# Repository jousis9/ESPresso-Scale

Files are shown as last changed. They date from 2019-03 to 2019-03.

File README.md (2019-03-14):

 **ESPresso Scale**  
Fully open source (s/w & h/w) scale project.

**Main repository of the project is on gitlab**  
https://gitlab.com/jousis/espresso-scale    
**Library only repository**  
https://gitlab.com/jousis/ads1232-library  

**Demo videos**
- https://www.youtube.com/watch?v=8tvMJu86iec
- https://www.youtube.com/watch?v=bEaxTo1kfss
- https://www.youtube.com/watch?v=PEWwwGYqkho
- https://www.youtube.com/watch?v=CMC78F73UXM
- https://www.youtube.com/watch?v=utdwb62cblk
- https://www.youtube.com/watch?v=FwshqRFPCWY
- https://www.youtube.com/watch?v=zp7rjEApNao
- many more coming soon

**Features**
- Open source firmware, software and hardware
- Two pcb designs, one with LED segment display and one with SPI connector (for OLED/TFT)
- Ionic v4 "beta" application with live weight display and full control of scale options (BLE)
- ESP32 (wroom module) MCU
- ADS1232 24-bit ADC from TI
- Lipo and USB powered
- 10SPS and 80SPS sampling speed with various options regarding filtering/smoothing
- Auto calibration function (selectable weight)
- Touch buttons , using ESP32 pins or external touch module (TTP223).
- OTA upgrade mode (wifi)
- 3d printed case (stl & fusion360 files provided)
- power consumption from 50mA under full use (TFT) to <1mA while on deep sleep

**What is provided ?**
- PCB Gerber file
- PCB pictures
- PCB assembly guide
- PCB layer drawings (top/bottom)
- Schematics (PDF)
- PCB easyEDA project export
- Fusion 360 project file for the cases
- stl files for the cases
- Assembly guide (basic)
- Bill of materials (BOM)
- Pinout reference
- Firmware (Arduino IDE project)
- Mobile Application (Ionic v4 source code)
- Basic ADC settings explanation file and some basic tests

**Documentation**  
All the source files have a lot of comments inside but I will upload separate, more detailed documents, soon.

**Consider contributing**  
I am not a developher, nor an EE.  
This project is intended as a kick start for the community to build something awesome.  
Feel free to change anything in any way you see fit.  
If you want to read more technical stuff and reasons why I did what I did, check out this [hackaday page](https://hackaday.io/project/164256-espresso-scale).  
I will try to upload details about all aspects of the design.  

**License**  
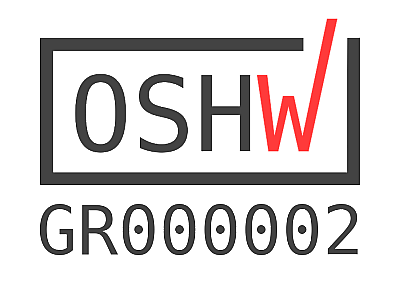
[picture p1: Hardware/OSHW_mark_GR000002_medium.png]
OSHW Certification
  
Software under [GPL v3](https://gitlab.com/jousis/espresso-scale/blob/master/LICENSE)  
Hardware under [CERN Open Hardware Licence v1.2](https://gitlab.com/jousis/espresso-scale/blob/master/hw-LICENSE)  
Documentation under [CC BY-SA license 2.0](https://creativecommons.org/licenses/by-sa/2.0/)

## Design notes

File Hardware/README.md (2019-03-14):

**About AVDD/Excitation voltage**  
I am testing 5V,4.3V LDOs for AVDD to see if the PCB can achieve +/-0.005 usable resolution when plugged in to 5V source.   
When my source voltage is 5V (usb wall charger) I get 4.73V on the AVDD LDO input (don't forget our BAT20J voltage drop). No need to force it to 3.3V (as in the proposed BOM).  
Note that the analog LDO gets its input directly from the P-Channel MOSFET and is not constrained by our digital voltage LDO. We can use 5V LDO for analog excitation voltage and 3.3 for the rest.  
The proposed TLV75533PDBVR for the DVDD we can go up to 5.5V input, so if you wish to increase the input voltage, be careful.  

**Upcoming changes (March 2019)**    
-Trying out touch button solutions because the internal capacitive sensors of ESP32 are not so good behind plastic.  
-I changed (again) the RC filters. X2Y are gone (are expensive, difficult to find and could not measure any difference) and I'm going back to 100% ADS1232 reference design with simple RC plus some more passthrough EMI filters (0805 on this section)

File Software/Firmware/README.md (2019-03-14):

  
**Some usefull documents from TI you should read**  
[ADS1232 datasheet](http://www.ti.com/lit/ds/symlink/ads1232.pdf)  
[ADS1232 Reference board User's Guide](http://www.ti.com/lit/ug/sbau120b/sbau120b.pdf)  
[High-Resolution, Low-Drift, Precision Weigh-Scale Reference Design with AC Bridge Excitation](http://www.ti.com/lit/ug/tiduac1a/tiduac1a.pdf)  

**Other libraries you might like**  

HX711 library from olkal and with a simple and efficient filtering function (moving average with High/Low Rejection)  
https://github.com/olkal/HX711_ADC  
  
If you need more channels and a more elaborate ADC read function, check out ADS123X library by Hamid Saffari  
https://github.com/HamidSaffari/ADS123X  
  
Another ADS1232 library with different approach (spitransfer) from jeffkub  
https://github.com/jeffkub/beer-gauge/tree/master/firmware/beer-gauge  
  
And last but not least, the famous HX711 from bodge  
https://github.com/bogde/HX711

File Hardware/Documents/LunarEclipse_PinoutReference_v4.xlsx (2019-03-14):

PIN | GPIO | ALT NAME | WARNING | TOUCH | I/O | INT PULLUP/PULLDOWN | H/W SPI | RTC | ADC | SCALE FUNCTION
4 | 36 | SVP |  |  | I | N |  | RTC_GPIO0 | 1
5 | 39 | SVN |  |  | I | N |  | RTC_GPIO3 | 1
6 | 34 |  |  |  | I | N |  | RTC_GPIO4 | 1
7 | 35 |  |  |  | I | N |  | RTC_GPIO5 | 1
8 | 32 |  |  | T9 | I/O |  |  | RTC_GPIO9 | 1 | T9
9 | 33 |  |  | T8 | I/O |  |  | RTC_GPIO8 | 1 | T8
10 | 25 |  |  |  | I/O |  |  | RTC_GPIO6 | 2
11 | 26 |  |  |  | I/O |  |  | RTC_GPIO7 | 2
12 | 27 |  |  | T7 | I/O |  |  | RTC_GPIO17 | 2
13 | 14 | HSPI SCK |  | T6 | I/O |  | 1 | RTC_GPIO16 | 2 | T6
14 | 12 | HSPI MISO | KEEP LOW ON RESET (DEFAULT) | T5 | I/O |  | 1 | RTC_GPIO15 | 2 | GAIN0
16 | 13 | HSPI MOSI |  | T4 | I/O |  | 1 | RTC_GPIO14 | 2 | GAIN1
17 | 9 |  | DO NOT USE |  | I/O
18 | 10 |  | DO NOT USE |  | I/O
19 | 11 |  | DO NOT USE |  | I/O
20 | 6 |  | DO NOT USE |  | I/O
21 | 7 |  | DO NOT USE |  | I/O
22 | 8 |  | DO NOT USE |  | I/O
23 | 15 | HSPI SS / MTDO | KEEP HIGH ON RESET (DEFAULT) | T3 | I/O |  | 1 | RTC_GPIO13 | 2
24 | 2 |  | KEEP LOW ON RESET (DEFAULT) / IF HIGH CANNOT DOWNLOAD FIRMWARE | T2 | I/O |  |  | RTC_GPIO12 | 2
25 | 0 | boot |  | T1 | I/O |  |  | RTC_GPIO11 | 2 | IO0 button
26 | 4 |  |  | T0 | I/O |  |  | RTC_GPIO10 | 2 | ADC_PDWN
27 | 16 |  |  |  | I/O |  |  |  |  | ADC_DOUT
28 | 17 |  |  |  | I/O |  |  |  |  | ADC_SCLK
29 | 5 | VSPI SS |  |  | I/O |  | 2 |  |  | MAX7221 CS
30 | 18 | VSPI SCK |  |  | I/O |  | 2 |  |  | MAX7221 CLK
31 | 19 | VSPI MISO |  |  | I/O |  | 2
33 | 21 |  |  |  | I/O
34 | 3 | RXD | NC |  | I/O |  |  |  |  | RXD0
35 | 1 | TXD | NC |  | I/O |  |  |  |  | TXD0
36 | 22 |  |  |  | I/O |  |  |  |  | ADC_SPEED
37 | 23 | VSPI MOSI | or D1 or SDI |  | I/O |  | 2 |  |  | MAX7221 INPUT

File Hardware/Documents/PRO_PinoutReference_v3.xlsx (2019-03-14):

PIN | GPIO | ALT NAME |  | WARNING | TOUCH | I/O | INT PULLUP/PULLDOWN | H/W SPI | RTC | ADC | SCALE FUNCTION
4 | 36 | SVP |  |  |  | I | N |  | RTC_GPIO0 | 1 | BAT_CHECK
5 | 39 | SVN |  |  |  | I | N |  | RTC_GPIO3 | 1
6 | 34 |  |  |  |  | I | N |  | RTC_GPIO4 | 1
7 | 35 |  |  |  |  | I | N |  | RTC_GPIO5 | 1
8 | 32 |  |  |  | T9 | I/O |  |  | RTC_GPIO9 | 1 | T9 / CN8
9 | 33 |  |  |  | T8 | I/O |  |  | RTC_GPIO8 | 1 | T8 / CN7
10 | 25 |  |  |  |  | I/O |  |  | RTC_GPIO6 | 2 | SCREEN_BL
11 | 26 |  |  |  |  | I/O |  |  | RTC_GPIO7 | 2 | SCREEN_DC
12 | 27 |  |  |  | T7 | I/O |  |  | RTC_GPIO17 | 2 | SCREEN_RES
13 | 14 | HSPI SCK | OLED D0 or SCK or CLK or SCL |  | T6 | I/O |  | 1 | RTC_GPIO16 | 2 | SCREEN_SCL
14 | 12 | HSPI MISO | OLED SDO | KEEP LOW ON RESET (DEFAULT) | T5 | I/O |  | 1 | RTC_GPIO15 | 2 | T5 / CN6
16 | 13 | HSPI MOSI | OLED D1 or SDA or DIN |  | T4 | I/O |  | 1 | RTC_GPIO14 | 2 | SCREEN_SDA
17 | 9 |  |  | DO NOT USE |  | I/O
18 | 10 |  |  | DO NOT USE |  | I/O
19 | 11 |  |  | DO NOT USE |  | I/O
20 | 6 |  |  | DO NOT USE |  | I/O
21 | 7 |  |  | DO NOT USE |  | I/O
22 | 8 |  |  | DO NOT USE |  | I/O
23 | 15 | HSPI SS / MTDO |  | KEEP HIGH ON RESET (DEFAULT) | T3 | I/O |  | 1 | RTC_GPIO13 | 2 | SCREEN_CS
24 | 2 |  |  | KEEP LOW ON RESET (DEFAULT) / IF HIGH CANNOT DOWNLOAD FIRMWARE | T2 | I/O |  |  | RTC_GPIO12 | 2 | INDICATOR LED
25 | 0 | boot |  |  | T1 | I/O |  |  | RTC_GPIO11 | 2 | IO0 button
26 | 4 |  |  |  | T0 | I/O |  |  | RTC_GPIO10 | 2
27 | 16 |  |  |  |  | I/O |  |  |  |  | ADC_GAIN0
28 | 17 |  |  |  |  | I/O |  |  |  |  | ADC_GAIN1
29 | 5 | VSPI SS |  |  |  | I/O |  | 2 |  |  | ADC_PDWN
30 | 18 | VSPI SCK |  |  |  | I/O |  | 2 |  |  | ADC_SCLK
31 | 19 | VSPI MISO |  |  |  | I/O |  | 2 |  |  | ADC_DOUT
33 | 21 |  |  |  |  | I/O |  |  |  |  | ADCLDO_EN
34 | 3 | RXD |  | NC |  | I/O |  |  |  |  | RXD0
35 | 1 | TXD |  | NC |  | I/O |  |  |  |  | TXD0
36 | 22 |  |  |  |  | I/O |  |  |  |  | ADC_SPEED
37 | 23 | VSPI MOSI |  | or D1 or SDI |  | I/O |  | 2 |  |  | BAT_CHECK_EN

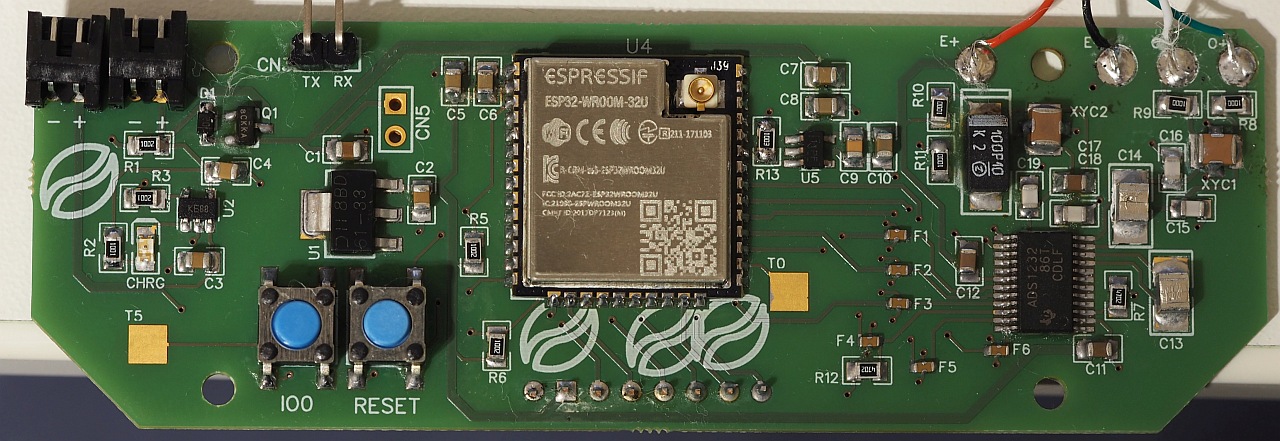
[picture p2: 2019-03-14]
Hardware/PCB Images/PRO v2/top_small.jpg

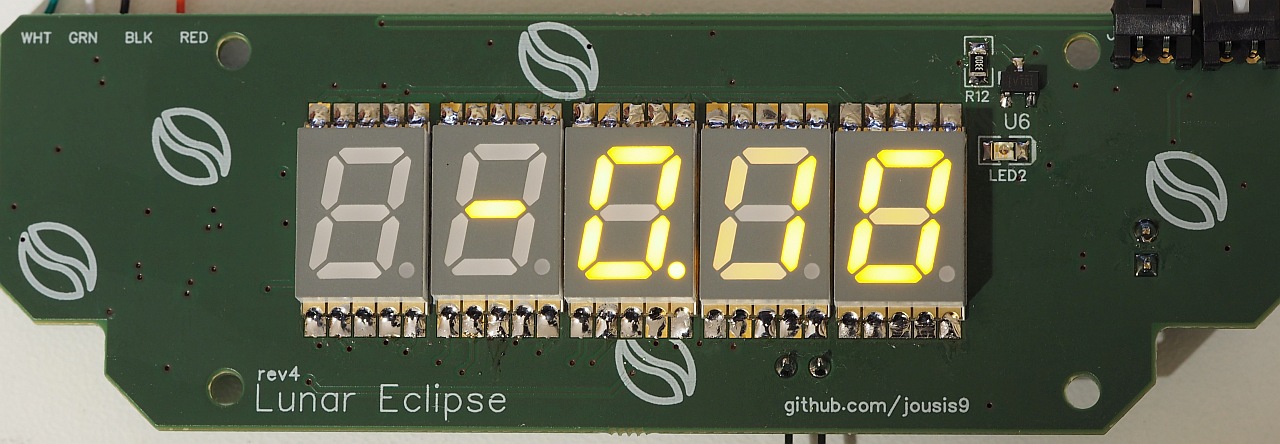
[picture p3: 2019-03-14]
Hardware/PCB Images/Lunar Eclipse v4/bottom_small.jpg

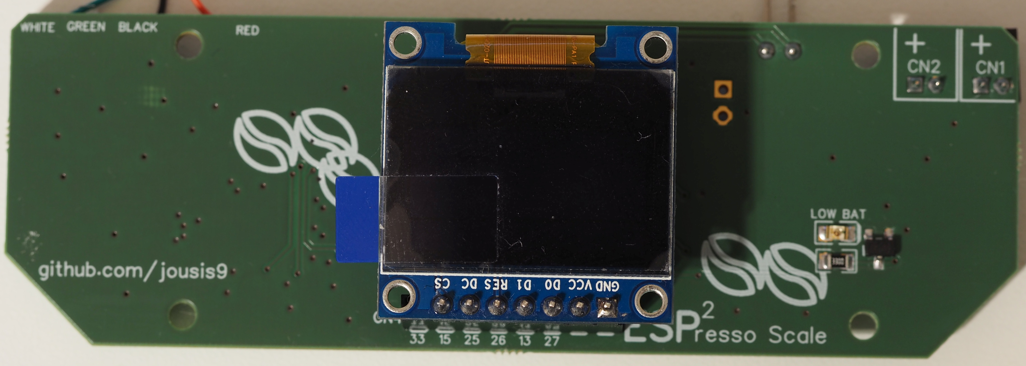
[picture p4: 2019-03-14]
Hardware/PCB Images/PRO v2/bottom02.jpg

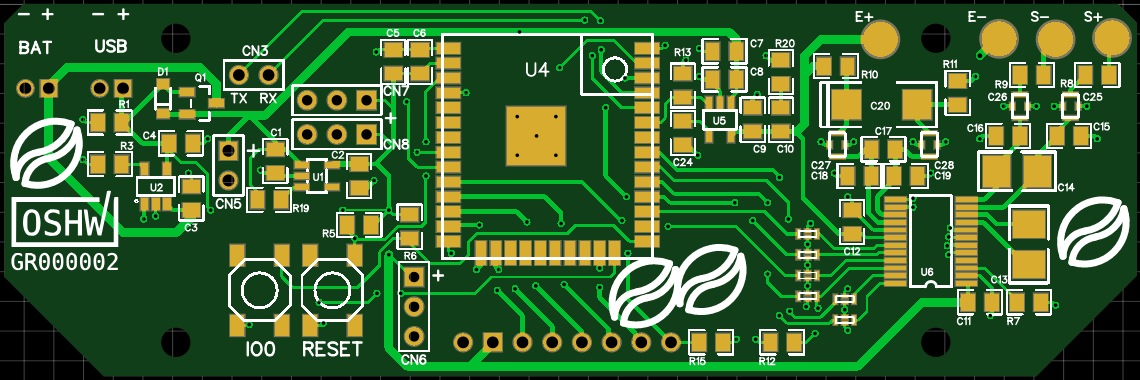
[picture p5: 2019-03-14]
Hardware/PCB Layers/PRO v3/TopRender.jpg

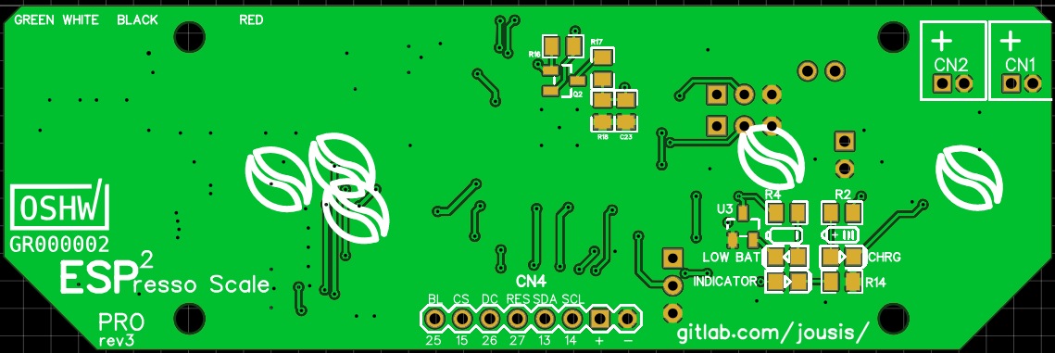
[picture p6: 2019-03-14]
Hardware/PCB Layers/PRO v3/BottomRender.jpg

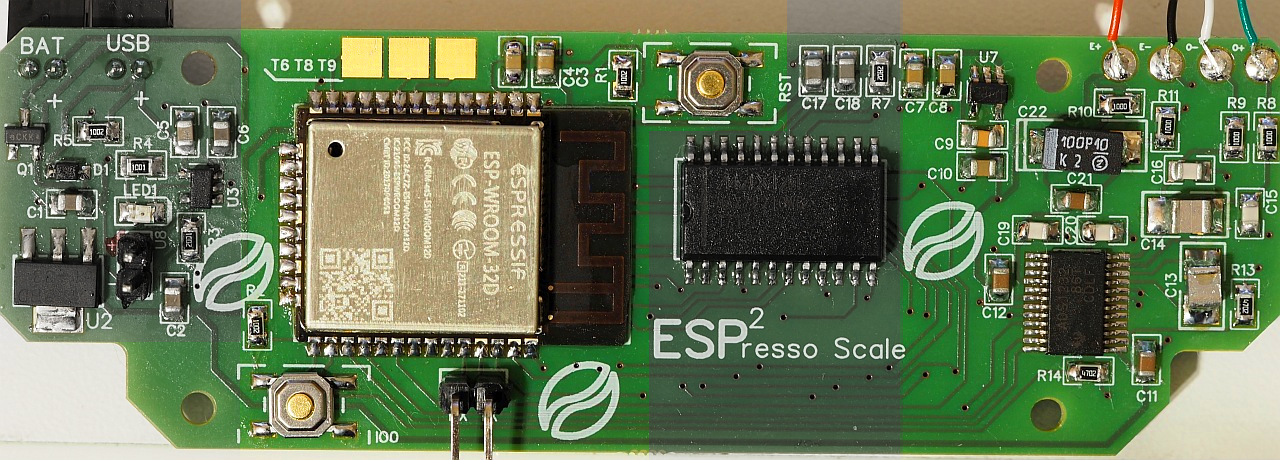
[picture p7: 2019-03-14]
Hardware/PCB Images/Lunar Eclipse v4/top_sections.jpg

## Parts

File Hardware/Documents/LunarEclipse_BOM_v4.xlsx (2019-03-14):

ID | Name | Designator | Footprint | quick info | Quantity | Can I use cheaper ? | Manufacturer Part | Manufacturer | Supplier | cost (euro for 1 unit) | Supplier URL
1 | VDMY10C0 | 7SEG1,7SEG2,7SEG3,7SEG4,7SEG5 | VDMY10C0 |  | 5 | YES | KCSC03-106 | VISHAY | mouser | 7.75 | https://gr.mouser.com/ProductDetail/VDMY10C0/
2 | Mini Push Button | BOOT,RESET | SMD-BUTTON |  | 2 | Definitely, I just like them a lot. Check the buttons of PRO version. | COM-08720 | SparkFun Electronics | mouser | 1.66 | https://gr.mouser.com/ProductDetail/COM-08720/
3 | 4.7uF | C1,C2,C6 | 0805 | 4.7uF, 16V | 3 | YES | GRM21BR71C475KE51L | murata | mouser | 0.63 | https://gr.mouser.com/ProductDetail/GRM21BR71C475KE51L/
4 | 10uF | C3,C7,C10,C17 | 0805 | 10uF, 16V | 4 | YES | GRM21BC81C106KE15K | murata | mouser | 0.664 | https://gr.mouser.com/ProductDetail/GRM21BC81C106KE15K/
5 | 0.1uF | C4,C8,C18 | 0805 | 0.1uF, 16V | 3 | YES | CC0805JRX7R7BB104 | yageo | mouser | 0.471 | https://gr.mouser.com/ProductDetail/CC0805JRX7R7BB104/
6 | 10nF | C9 | 0805 | 0.01uF (10nF), 50V | 1 | YES | 885012207092 | Wurth | mouser | 0.08 | https://gr.mouser.com/ProductDetail/710-885012207092/
7 | 2.2uF | C11,C12,C21 | 0805 | 2.2uF, 16V | 3 | YES | GCM21BR71A225JA37L | murata | mouser | 1.101 | https://gr.mouser.com/ProductDetail/GCM21BR71A225JA37L/
8 | 0.1uF PPS | C13,C14 | 1210 | 0.1uF PPS, 16V | 2 | Might lose accuracy/stability | ECH-U1C104GX5 | Panasonic | mouser | 1.484 | https://gr.mouser.com/ProductDetail/667-ECH-U1C104GX5/
9 | 1uF | C5 | 0805 | 1uF, 16V | 1 | YES | GRM21BR71C105JA01K | murata | mouser | 0.157 | https://gr.mouser.com/ProductDetail/GRM21BR71C105JA01K/
10 | 100pF NP0 | C15,C16,C19,C20 | 0805 | 100pF, NP0, 50V, 1% | 4 | Might lose accuracy/stability | GRM2165C1H101FA01D | Murata | mouser | 0.664 | https://gr.mouser.com/ProductDetail/0805YA101FAT2A/
11 | 100uF (T) | C22 | Case C | 100uF, Tantalum, 10V | 1 | YES | TP3C107K010D0900AS | VISHAY | mouser | 0.568 | https://gr.mouser.com/ProductDetail/TP3C107K010D0900AS/
12 | BAT20JFILM | D1 | SOD-323 |  | 1 | YES | BAT20JFILM | STMicroelectronics | mouser | 0.332 | https://gr.mouser.com/ProductDetail/BAT20JFILM/
13 | DF3A-2P-2DS | CN1,CN2 |  |  | 2 | YES | DF3A-2P-2DS | Hirose | mouser | 0.175 | https://gr.mouser.com/ProductDetail/DF3A-2P-2DS/ | 2mm pitch, 0.8mm hole. DF3A-2P-2DS(16) ==> right angle, tin plating , blue color, DF3A-2P-2DS ==> right angle, black , df3-2p-2ds(01) ==> right angle, gold plating, black NOTE: DS ==> right angle DSA==> straight
14 | Yellow | LED1 | 0805 | 2V, 20mA | 1 | YES | 150080YS75000 | Wurth | mouser | 0.16 | https://gr.mouser.com/ProductDetail/150080YS75000/
15 | Red | LED2 | 0805 | 1.75V , for low battery warning | 1 | YES | APTD2012LSURCK | Kingbright | mouser | 0.402 | https://gr.mouser.com/ProductDetail/604-APTD2012LSURCK
16 | SQ2303ES-T1_GE3 | Q1 | SOT-23(SOT-23-3) |  | 1 | YES | SQ2303ES-T1_GE3 | VISHAY | mouser | 0.437 | https://gr.mouser.com/ProductDetail/SQ2303ES-T1_GE3/
17 | 10K | R1,R2,R5 | 0805 | 10K, 1% | 3 | YES | ERJ-6ENF1002V | Panasonic | mouser | 0.261 | https://gr.mouser.com/ProductDetail/ERJ-6ENF1002V/
18 | 2K | R3 | 0805 | 2K, 1% | 1 | YES | ERJ-6ENF2001V | Panasonic | mouser | 0.087 | https://gr.mouser.com/ProductDetail/ERJ-6ENF2001V/
19 | 1K | R4 | 0805 | 1K, 1% | 1 | YES | ERJ-6ENF1001V | Panasonic | mouser | 0.087 | https://gr.mouser.com/ProductDetail/ERJ-6ENF1001V/
20 | 47K | R13,R14 | 0805 | 47K,1% | 2 | YES | ERJ-6ENF4702V | Panasonic | mouser | 0.49 | https://www.mouser.com/ProductDetail/667-ERJ-6ENF4702V/
21 | 28K (production) | R7 | 0805 | alternative : 18K ERJ-6GEYJ183V | 1 | YES | ERJ-6ENF2802V | Panasonic | mouser | 0.236 | https://gr.mouser.com/ProductDetail/ERJ-6ENF2802V/
22 | 100R | R8,R9,R10,R11 | 0805 | 100R, 1% | 4 | Might lose accuracy/stability | ERJ-6ENF1000V | Panasonic | mouser | 0.348 | https://gr.mouser.com/ProductDetail/ERJ-6ENF1000V/
23 | 330R | R12 | 0805 | 330R | 1 | YES | CRCW0805330RFKEAC | VISHAY | mouser | 0.087 | https://gr.mouser.com/ProductDetail/71-CRCW0805330RFKEAC/
24 | ESP32-WROOM-32D | U1 | ESP32_WROOM_FOOTPRINT |  | 1 | YES | ESP32-WROOM-32D | Espressif | mouser | 3.32 | https://gr.mouser.com/ProductDetail/356-ESP32WROOM-32D/
25 | AP7361C-33E-13 | U2 | SOT223-4 | main LDO (1A) | 1 | YES | AP7361C-33E-13 | Diodes Incorporated | mouser | 0.498 | https://gr.mouser.com/ProductDetail/AP7361C-33E-13/
26 | MCP73831T-2ATI/OT | U3 | SOT-23-5 |  | 1 | YES | MCP73831T-2ATI/OT | MICROCHIP | mouser | 0.507 | https://gr.mouser.com/ProductDetail/MCP73831T-2ATI-OT/
27 | ADS1232IPWR | U4 | TSSOP-24 |  | 1 | r u kidding me ? | ADS1232IPWR | TI | mouser | 7.13 | https://gr.mouser.com/ProductDetail/ADS1232IPWR/
28 | MAX7221CWG+ | U5 | SOIC-24 |  | 1 | YES | MAX7221CWG+ | maxim integrated | mouser | 8.03 | https://gr.mouser.com/ProductDetail/700-MAX7221CWG/
29 | Voltage supervisor | U6 | SOT-23-3 | 2.93V, Active-low,Push-pull | 1 | Yes, you can also completely remove it, along with LED2 and R12 | TLV809K33DBVR | TI | mouser | 0.576 | https://gr.mouser.com/ProductDetail/595-TLV809K33DBVR
30 | TPS7A0533PDBVR | U7 | SOT-23-5 | ADC LDO (200mA) | 1 | Yes, use any other, but of high quality | TPS7A0533PDBVR | TI | mouser | 0.515 | https://gr.mouser.com/ProductDetail/595-TPS7A0533PDBVR/
31 | lipo battery |  |  | 1600mAh | 1 | YES |  |  | grobotronics | 12 | https://grobotronics.com/polymer-lithium-ion-battery-3.7v-1600mah.html
32 | load cell |  |  | 200g-500g high precision for espresso, 500g+ for other | 1 | YES |  |  | aliexpress | 4 | https://www.aliexpress.com/item/200g-small-range-high-precision-weighing-sensor-load-cell-weight-sensor/32746278566.html
 | Male headers 1x2 for VIN (optional) | U8 |  |  |  |  |  | Total Cost |  | 54.91 | excl VAT
 | Male headers 1x2 for serial | U9

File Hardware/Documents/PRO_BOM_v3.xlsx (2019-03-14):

ID | Name | Designator | Footprint | quick info | Quantity | Try Cheaper ? | Manufacturer Part | Manufacturer | Supplier | cost (euro for 1 unit) | Supplier URL
1 | 4.7u | C2,C3,C4,C10 | 0805 | 4.7uF, 16V | 4 | YES | GRM21BR71C475KE51L | murata | mouser | 0.84 | https://gr.mouser.com/ProductDetail/GRM21BR71C475KE51L/
2 | 1u | C1,C7 | 0805 | 1uF, 16V | 2 | YES | GRM21BR71C105JA01K | murata | mouser | 0.314 | https://gr.mouser.com/ProductDetail/GRM21BR71C105JA01K/
3 | 10u | C5 | 0805 | 10uF, 16V | 1 | YES | GRM21BC81C106KE15K | murata | mouser | 0.166 | https://gr.mouser.com/ProductDetail/GRM21BC81C106KE15K/
4 | 0.1u | C6,C8,C23 | 0805 | 0.1uF, 16V | 3 | YES | CC0805JRX7R7BB104 | yageo | mouser | 0.471 | https://gr.mouser.com/ProductDetail/CC0805JRX7R7BB104/
5 | 10n | C9 | 0805 | 0.01uF (10nF), 50V | 1 | YES | 885012207092 | Wurth | mouser | 0.08 | https://gr.mouser.com/ProductDetail/710-885012207092/
6 | 10n | C24 | 0805 | Optional 0.01uF for low noise, read assembly guide | 1 | YES | 885012207092 | Wurth | mouser | 0.08 | https://gr.mouser.com/ProductDetail/710-885012207092/
7 | 2.2u | C17 | 0805 | 2.2uF, 16V | 1 | Might lose accuracy/stability | GCM21BR71A225JA37L | murata | mouser | 0.367 | https://gr.mouser.com/ProductDetail/GCM21BR71A225JA37L/
8 | 2.2u | C11,C12 | 0805 | 2.2uF, 16V | 2 | YES | VJ0805G225KXQTW1BC | VISHAY | mouser | 0.314 | https://gr.mouser.com/ProductDetail/77-VJ0805G225KXQTBC/
9 | 0.1u PPS ECH-U1C104GX5 | C13,C14 | 1210 | 0.1uF PPS, 16V | 2 | Might lose accuracy/stability | ECH-U1C104GX5 | Panasonic | mouser | 1.484 | https://gr.mouser.com/ProductDetail/667-ECH-U1C104GX5/
10 | 100p NP0 | C15,C16,C18,C19 | 0805 | 100pF, NP0, 50V, 1% | 4 | Might lose accuracy/stability | GRM2165C1H101FA01D | Murata | mouser | 0.664 | https://gr.mouser.com/ProductDetail/GRM2165C1H101FA01D/
11 | 100uF (T) | C20 | Case C | 100uF, Tantalum, 10V | 1 | YES | TP3C107K010D0900AS | VISHAY | mouser | 0.568 | https://gr.mouser.com/ProductDetail/TP3C107K010D0900AS/
12 | 1u feed through | C25,C26,C27,C28 | 0805 | 1uF Feed through | 4 | Might lose accuracy/stability | NFM21PC105B1C3D | Murata | mouser | 0.84 | https://gr.mouser.com/ProductDetail/NFM21PC105B1C3D/
13 | DF3A-2P-2DS | CN1,CN2 | DF3A-2P-2DS | power/battery connector | 2 | YES | DF3A-2P-2DS | Hirose | mouser | 0.175 | https://gr.mouser.com/ProductDetail/DF3A-2P-2DS/
14 | 2.54_HEADER_2P | CN3,CN5 | 2P_2.54 | serial/5V bypass power | 1
15 | Header-M2.54_1x8 | CN4 | 210S-1X8P | oled/tft SPI connector | 1
16 | Header1x3_2.54 | CN6,CN7,CN8 |  | external buttons | 3
17 | BAT20JFILM | D1 | SOD-323 |  | 1 | YES | BAT20JFILM | STMicroelectronics | mouser | 0.332 | https://gr.mouser.com/ProductDetail/BAT20JFILM/
18 | 100pF feed through | F1,F2,F3,F4,F5,F6 | 0603 | feed through caps for the digital signal lines of the ADC. Works fine without them. | 6 | Yes,you can also omit them but be carefull not to short with G when using bypass cable :) | NFM18CC101R1C3D | MuRata | mouser | 1.572 | https://gr.mouser.com/ProductDetail/81-NFM18CC101R1C3D/
19 | CHRG | LED1 | 0805 | 2V, 20mA | 1 | YES | 150080YS75000 | Wurth | mouser | 0.16 | https://gr.mouser.com/ProductDetail/150080YS75000/
20 | LOW BAT | LED2 | 0805 | 1.75V , for low battery warning | 1 | YES | APTD2012LSURCK | Kingbright | mouser | 0.402 | https://gr.mouser.com/ProductDetail/604-APTD2012LSURCK/
21 | INDICATOR | LED3 | 0805 | 2V, 20mA | 1 | Yes, you can also omit it | 150080BS75000 | Wurth | mouser | 0.16 | https://gr.mouser.com/ProductDetail/150080BS75000/
22 | SQ2303ES-T1_GE3 | Q1,Q2 | SOT-23(SOT-23-3) |  | 2 | YES | SQ2303ES-T1_GE3 | VISHAY | mouser | 0.874 | https://gr.mouser.com/ProductDetail/SQ2303ES-T1_GE3/
23 | 10k | R1,R5,R6,R17,R18 | 0805 | 10K, 1% | 5 | YES | ERJ-6ENF1002V | Panasonic | mouser | 0.435 | https://gr.mouser.com/ProductDetail/ERJ-6ENF1002V/
24 | 1k | R2,R15 | 0805 | 1K, 1% | 1 | YES | ERJ-6ENF1001V | Panasonic | mouser | 0.087 | https://gr.mouser.com/ProductDetail/ERJ-6ENF1001V/
25 | 2k | R3 | 0805 | 2K, 1% | 1 | YES | ERJ-6ENF2001V | Panasonic | mouser | 0.087 | https://gr.mouser.com/ProductDetail/667-ERJ-6ENF2001V/
26 | 330R | R4,R14 | 0805 | 330R, 1% | 1 | YES | CRCW0805330RFKEAC | VISHAY | mouser | 0.087 | https://gr.mouser.com/ProductDetail/71-CRCW0805330RFKEAC/
27 | 47K | R7,R12 | 0805 | 47K,1% | 2 | YES | ERJ-6ENF4702V | Panasonic | mouser | 0.49 | https://www.mouser.com/ProductDetail/667-ERJ-6ENF4702V/
28 | 100R | R10,R11 | 0805 | 100R, 1% | 4 | YES | ERJ-6ENF1000V | Panasonic | mouser | 0.348 | https://gr.mouser.com/ProductDetail/ERJ-6ENF1000V/
29 | 0R | R8,R9 | 0805 | 0R, 1% | 2 | YES | RC0805FR-130RL | Yageo | mouser | 0.192 | https://gr.mouser.com/ProductDetail/603-RC0805FR-130RL/
30 | 100K | R13,R16,R19 | 0805 | 100K, 1% | 3 | YES | ERJ-6ENF1003V | Panasonic | mouser | 0.261 | https://gr.mouser.com/ProductDetail/667-ERJ-6ENF1003V/
31 | ???R | R20 | 0805 | optional, to add some R to the output of the LDO. More info on assembly guide.
32 | RESET | SW1 |  |  | 1 | YES | PTS525SM15SMTR2LFS | C&K | mouser | 0.288 | https://gr.mouser.com/ProductDetail/611-PTS525SM15SMTR2/
33 | IO0 | SW2 |  |  | 1 | YES | PTS525SM15SMTR2LFS | C&K | mouser | 0.288 | https://gr.mouser.com/ProductDetail/611-PTS525SM15SMTR2/
34 | TLV75533PDBVR | U1 | SOT-23-5 | main LDO (500mA) | 1 | YES | TLV75533PDBVR | TI | mouser | 0.541 | https://gr.mouser.com/ProductDetail/595-TLV75533PDBVR/
35 | MCP73831T-2ATI/OT | U2 | SOT-23-5 |  | 1 | YES | MCP73831T-2ATI/OT | MICROCHIP | mouser | 0.507 | https://gr.mouser.com/ProductDetail/MCP73831T-2ATI-OT/
36 | TLV809K33DBVR | U3 | SOT-23-3 | 2.93V, Active-low,Push-pull | 1 | Yes, it is only for low battery warning... you can completely remove it, along with LED2 and R12 | TLV809K33DBVR | TI | mouser | 0.576 | https://gr.mouser.com/ProductDetail/595-TLV809K33DBVR
37 | ESP32_ESP_WROOM_32U | U4 | ESP32_ESP_WROOM_32U |  | 1 | Yes, use any other with same footprint (ex. 32D with antenna) | ESP32-WROOM-32U | Espressif | mouser | 3.49 | https://gr.mouser.com/ProductDetail/ESP32-WROOM-32U/
38 | TPS7A0533PDBVR | U5 | SOT-23-5 | ADC LDO (200mA) | 1 | Yes, use any other, but of high quality. Try one with 4.7-5Voutput | TPS7A0533PDBVR | TI | mouser | 0.515 | https://gr.mouser.com/ProductDetail/595-TPS7A0533PDBVR/
39 | ADS1232IPWR | U6 | TSSOP-24 |  | 1 | r u kidding me ? | ADS1232IPWR | TI | mouser | 7.13 | https://gr.mouser.com/ProductDetail/ADS1232IPWR/
40 | OLED/TFT with SPI interface (can also use any other interface using the same pins). Be carefull with VCC/GND pins. Might be the other way around. |  |  |  | 1 | YES |  |  | aliexpress | 3 | https://www.aliexpress.com/item/IPS-0-96-inch-7P-SPI-HD-65K-Full-Color-LCD-Module-ST7735-Drive-IC-80/32859445140.html
41 | lipo battery |  |  | 1600mAh | 1 | YES |  |  | grobotronics | 12 | https://grobotronics.com/polymer-lithium-ion-battery-3.7v-1600mah.html
42 | antenna |  |  | Optional, will work without in close range | 1 | YES | ANTX100P011B24003 | Yageo | mouser |  | https://gr.mouser.com/ProductDetail/603-ANTX100P011B2400/
43 | load cell |  |  | 200g-500g high precision for espresso, 500g++ for other | 1 | YES |  |  | aliexpress | 4 | https://www.aliexpress.com/item/200g-small-range-high-precision-weighing-sensor-load-cell-weight-sensor/32746278566.html
 |  |  |  |  |  |  |  | Cost (w/o VAT): |  | 40.185

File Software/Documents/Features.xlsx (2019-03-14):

 |  | Open Source ESPresso Scale
 | Quality Espresso Scale | Lunar Eclipse | PRO (v3)
Open source f/w | NO | YES ! | YES !
Open source h/w | NO | YES ! | YES !
BLE | propiertary API | YES ! | YES !
WiFi | NO | YES ! (for f/w upgrade) | YES ! (for f/w upgrade)
Battery input/charging | YES (lipo) | YES (lipo*) | YES (lipo*)
USB charging (<5.5V) | YES | YES | YES
USB Power Only | Kind of (with USB you get unstable readings) | YES, slight drift when charging at full current (**) | YES, slight drift when charging at full current (**)
Battery monitor / Low battery warning LED | YES (warning led + battery level) | Low battery warning LED | YES (warning led + battery level) | Battery level read is done on the VIN of the analog LDO. Not only we can detect if the voltage that goes to our (analog) LDO is < 3.3V (low accuracy) but we can also detect if it is >5V (high accuracy)
Numeric Display | Custom 8x7SEG | 5x 7SEG | 7SEG ? Are we in 90s ?
OLED Display (SPI connector) | NO | NO | YES !
IPS/TFT Display (SPI connector) | NO | NO | YES ! (with backlight control)
ADC for load cell | HX711 | TI ADS1232 | TI ADS1232
Sampling speed | Fixed 80SPS (?) | Selectable (10SPS/80SPS) | Selectable (10SPS/80SPS) | Software controlled, real time switch.
response time | 20ms (?) | from 12.5ms (configurable) | from 12.5ms (configurable) | Software controlled, real time switch.
calibration weight | 100g (only? ) | Selectable (BLE) | Selectable (BLE)
Touch buttons | 2 | 3 | 3 external Digital IO connectors | use external TTP223 touch modules for touch input
Normal buttons | 0 | 0 | 3 external Digital IO connectors | configure your internal pullups/pulldowns on the software accordingly
Optical feedback on touch | dot on screen | NO | optional led, optional on screen
Audible feedback on touch | YES | NO | NO
Firmware upgrade with USB | NO | Yes, with external FTDI*** | Yes, with external FTDI***
Firmware upgrade with BLE | YES | Possible (NI) | Possible (NI)
Firmware upgrade with WiFi | NO | YES ! | YES !
Android / IOS App | pretty, with many issues | Ionic v4 (Open Source) | Ionic v4 (Open Source)
Options | with on screen menu, app (?) | APP (BLE) | APP (BLE)
Housing | awesome | 3d printed | 3d printed
Load cell | good | whatever you buy**** | whatever you buy****
Load cell excitation voltage | 3.3V (iirc) | 3.3V - 5V | 3.3V - 5V | Totaly depends on your LDOs. Design supports various choises, read assembly guide (v3) for more info
Input voltage | 3.7V lipo/ 5V usb | 3.7V lipo/ 5V usb/ or more | 3.7V lipo/ 5V usb/ or more | Totaly depends on your LDOs. Design supports various choises, read assembly guide (v3) for more info
Power consumption
Normal use (avg - no BLE traffic - no WiFi) | 60mA (no info on ADC) |  | 50mA with spikes to 100mA with 100% TFT brightness (80SPS)
Snooze (dimmed display, ADC@4SPS, automatic wakeup) |  |  | 20mA with some spikes to 50mA
Light sleep (display off, ADC shutdown, ADC LDO shutdown, wakeup with touch) |  |  | 20mA with some spikes to 50mA | need to work on lowering that
Power consumption (deep sleep, everything except ULP is off, wakeup with touch) | <1mA (cannot measure it) | <1mA (cannot measure it) | <1mA (cannot measure it)
Time to wake up from snooze/light sleep/deep sleep |  | 250ms/2s/full bootup | 250ms/1s/full bootup
 | *note that the final accuracy depends on the output voltage of the (AVD) LDO. If your battery is running out and you have 3V input, output will be around 2.8V and you will have less accuracy.
 | **if you only want USB power, leave all charging components unpopulated and just connect 5V/G to U8/CN5
 | ***you need to solder 2pin header (TX/RX)
 | ****500g-750g is fine for espresso, 1-2kg for drip/pour over, 100g-200g for gold :D
 | Note: Power consumption measurements are done with a simple USB tester and are with 80MHz frequency. If you choose to compile with 240MHz, you will have approx 100% more in sleep modes.

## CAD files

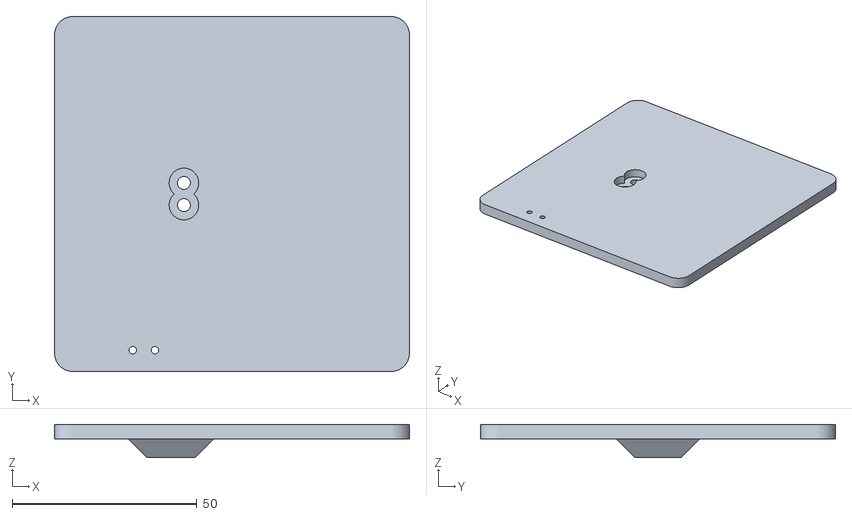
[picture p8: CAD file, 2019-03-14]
Hardware/case/STL/tal221_scale_bottom.stl
96.0 x 96.0 x 9.00

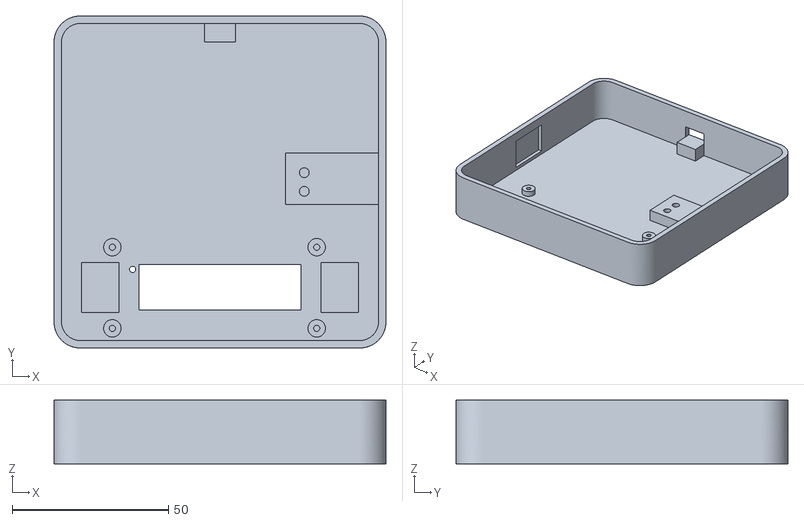
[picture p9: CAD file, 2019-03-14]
Hardware/case/STL/scale_top_7seg.stl
106.4 x 106.4 x 20.5

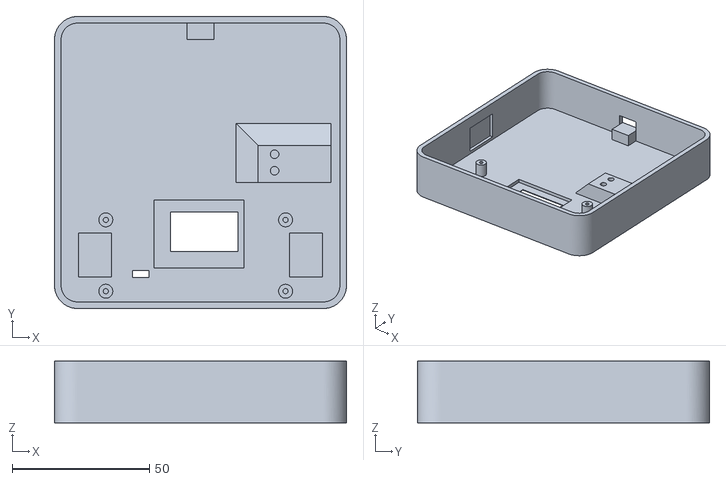
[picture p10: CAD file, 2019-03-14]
Hardware/case/STL/scale_top_ips.stl
106.4 x 106.4 x 22.5

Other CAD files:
Hardware/case/Fusion 360/ESPresso_Scale_v33.f3d

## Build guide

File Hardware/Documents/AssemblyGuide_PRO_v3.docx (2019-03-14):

ESP²resso Scale PRO

PCB Assembly Guide (v3)

WIP

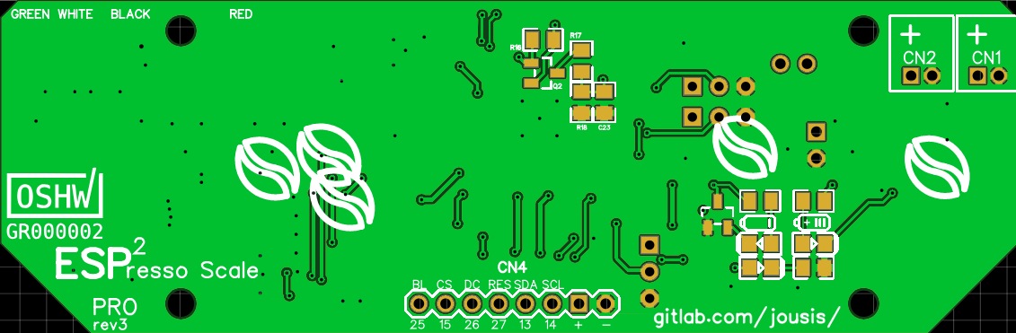
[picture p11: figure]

With a little care, you can easily hand solder all the components. No need for hot air.

If you want to minimize the cost, all components except the ADC can be replaced with cheaper alternatives. Try to avoid very cheap components in the analog section (RC filtering) or you might lose some accuracy/stability.

Why “espresso” scale?
High resolution, high refresh rate needed during an espresso extraction. Apart from that, it is a normal scale.

Why “PRO”?

You can use any SPI (or I2C) screen (even TFT with backlight pin), slightly better RC filtering, speed/gain control of the ADC from the software, better separation of analog/digital tracks, power on/off of the second LDO.

Section 1 – USB / Battery Input & charging

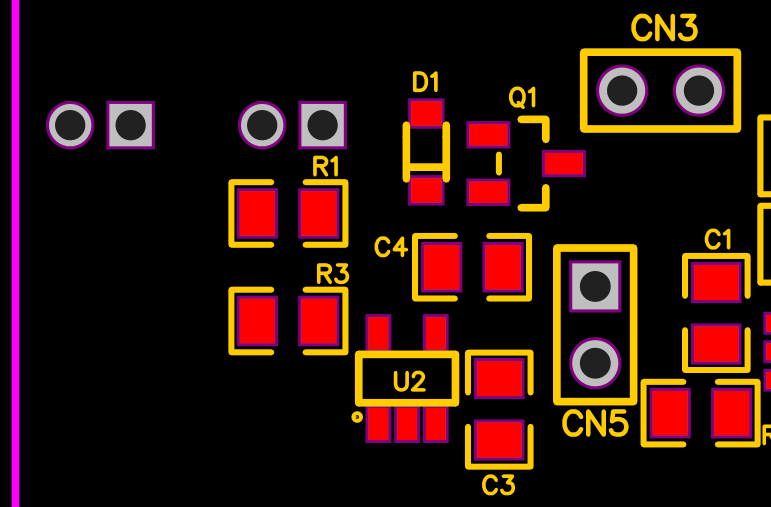
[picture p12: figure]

Battery charging circuit design: Sparkfun ESP32 Thing (https://cdn.sparkfun.com/assets/learn_tutorials/5/0/7/esp32-thing-schematic.pdf)

If you don’t care about battery / battery charging you can connect DC+5V to CN5 and do not solder any of the parts shown above.

Please see the schematics for more info.

Section 2 – LDO & MCU

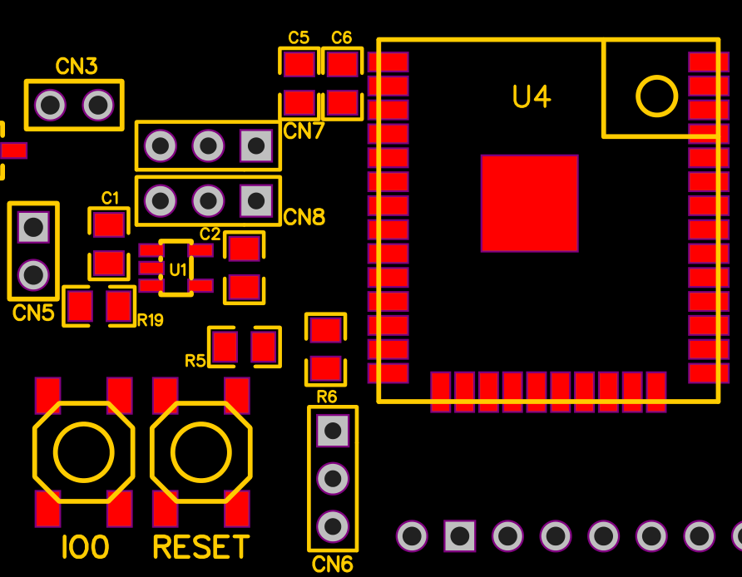
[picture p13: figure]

LDO (U1)

You can use any LDO pin-compatible with TLV75533PDBVR (SOT-23-5). You don’t need one with enable pin but if it has one, check its datasheet and:

- If it needs logic high for enable, solder R19 (100K). R19 goes to vin (C1).
- If it needs logic low solder a jumper cable from R19 right pad to GND of CN5.

CN5 is optional header, you can use it to give power to the LDO without having to connect the Section 1 part. Very handy for testing.

MCU (U4)

You can use any esp32 wroom with the same footprint (ESP32, ESP32D, ESP32U).
Why module (wroom) and not barebones chip?
Easier to solder, readily available, reasonable size.

Programming

The only way to program your MCU for the 1st time is through the serial connector on the bottom. There is no ftdi chip on the PCB. Afterwards, if you wish, you can setup an OTA method.

Touch Input

The middle pin of the three connectors CN6,CN7,CN8 goes to a touch pin of esp32 (T5,T8,T9). You can use them with internal capacitive methods if you prefer. Or…

Regular buttons/ External digital IO touch modules

CN6,CN7,CN8 provide an easy way to connect regular buttons using internal PULLUP/PULLDOWN or any external touch module with digital output. All three provide VCC(3.3V) / IO / GND.

Section 3 – ADC / Load Cell

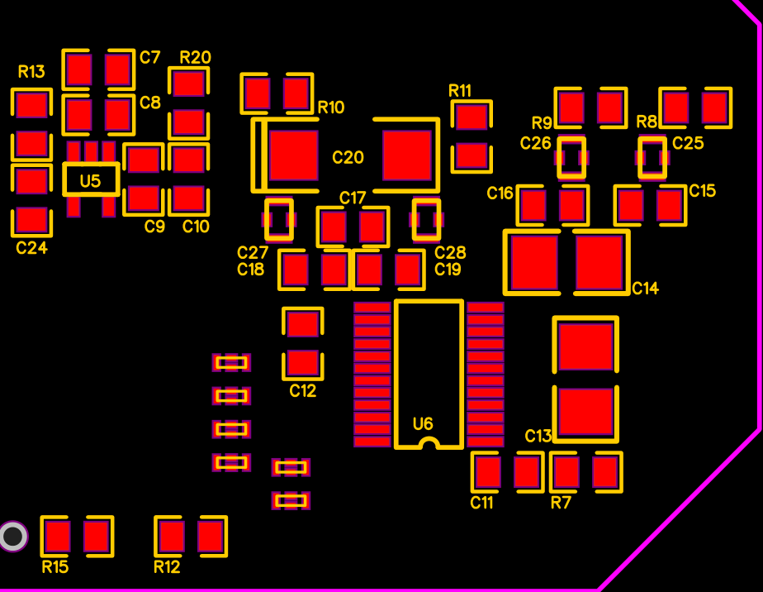
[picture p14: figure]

Analog Voltage LDO

U5 is the local LDO for the excitation voltage of the load cell (and reference voltage). Use high quality components on everything related to the analog circuit.

R20

Is there to add some resistance to C10 if you want to use MLCC and your LDO works better with some ESR (most). If you don’t want to use any R there (not even 0R?), solder bridge both pads.
Warning: C20 is not grounded. It goes to ground through R20.

C24

Completely optional. Only if your LDO had a need/option for Cnr capacitor to reduce its output noise. Check datasheet for correct value.

Comments on the analog LDO

You don’t have to use any of them but since this is a very crucial part of the scale, I like to share my thoughts and experiments.

Disclaimer: I know there is a pattern in my project with a special brand (TI) but I am not in any way affiliated to them, everything was paid using my own money. I cannot deny though that I really like the quality and specs of their components.

Option 1 – OK for battery use (BOM)

TPS7A0533PDBVR

200mA 3.3V with 210mV dropout and 1uA Iq while working (0.1A on shutdown). Good all around. You can use this LDO only with 5V input (max Input 5.5V). Place 0R on R20 or solder bridge the pads, leave C24 unpopulated.

I used this LDO with most of my tests, works well but it is nothing extraordinary. If your main use is battery, excitation voltage cannot go above 3.3V (maybe slightly) so 3.3V regulator is all we need.

Option 2 – OK for battery use

TLV75533PDBVR

500mA 3.3V with 210mV dropout and 25uA Iq while working (0.1A on shutdown). Good all around. You can use this LDO only with 5V input (max Input 5.5V). Place 0R on R20 or solder bridge the pads, leave C24 unpopulated.

I used this LDO with most of my tests, works well but it is nothing extraordinary. If your main use is battery, excitation voltage cannot go above 3.3V (maybe slightly) so 3.3V regulator is all we need.

Note: you can use this LDO for both analog and digital, reducing the parts you will need to buy.

Option 3 – OK for mixed use (DC / Battery)

TPS76950DBVR

100mA 5V with 70mV dropout, 17uA while working (1uA on shutdown). Its max input V is 10V so if you provide 7V+ input you will have 5V excitation voltage for our load cell. The same LDO will work fine on battery but if you don’t intend to provide DC input on the scale, prefer the TPS7A for its low Iq. Place 0R on R20 or solder bridge the pads, leave C24 unpopulated.

Advantages:

- Up to 5V excitation voltage (with 10V>Vin>7V) for increased accuracy
- Very low dropout voltage

Disadvantages:

- Works fine on battery due to its relatively low Iq but not as well as option1

Option 4 – Low noise – mixed use

TPS73643DBVR (4.3V) or TPS73633DBVR (3.3V)

400mA with 75mV dropout and 500uA ground current while working, 0.02uA on shutdown. With C24 (0.01uF) this LDO has very low noise on output. The drawback is its very high ground current while working. For short periods on, large periods off (espresso), it is a viable option. Also note its impressive shutdown current (0.02uA). TPS73643DBVR is the optimal solution here for mixed use (battery/5V DC). You will get 4.3V excitation voltage while on DC for increased accuracy. Place 0R on R20 or solder bridge the pads.

Warning: check firmware options, this LDO needs LOW for enable and HIGH for disable.

Advantages:

- Up to 4.3V excitation voltage (max Vin 5.5V)
- Very low noise if you populate C24 (0.01uF)
- Very low shutdown current
- Very low dropout voltage
- 3.3V can be used as a main LDO as well, reducing the parts you need to buy (not recommended)

Disadvantages:

- Very high ground current while working. Not recommended for prolonged use while on battery. Decrease light/deep sleep timeout on firmware (those two options shut down the ADC LDO). Not recommended for use as main LDO (0.5mA consumption is a lot)
- Very expensive, low availability

Option 5 – DC input only (<16V)

LP2985-50DBVR (5V) – not tested yet

150mA with 280mV dropout and 850uA ground current (0.01uA on shutdown). Since we don’t mind about dropout and ground current, this LDO is a good option because of its low noise and stable operation with MLCC. Place 0R on R20 and 0.01uF capacitor on C24.

Warning: proposed main LDO cannot accept >5.5V. You will need to change it as well (see SPX3819M5-L-3-3)

Advantages:

- Up to 5V excitation voltage for increased accuracy
- Wide DC input voltage (<16V)
- Very low noise if you populate C24 (0.01uF)
- Very low shutdown current
- Good price (especially in quantity), good availability.

Disadvantages:

- Very high ground current while working

ADC

Compared to the HX711 used in almost all the cheap (and not) designs, ADS1232 from TI is very accurate and stable. Although much more expensive, for this type of scale it is an expense you will have to make. Even when heating it up it could manage 0.1g accuracy (has internal temp sensor). Kudos to TI for their awesome documentation and white papers. (notice: This project is in no way affiliated with TI)

Digital +3.3V comes from the main LDO, analog +3.3V from the local LDO. There is only one ground for both signals (analog/digital) but I tried to avoid any digital signal return path through the analog part of the ADC. Unfortunately, due to the size constraints and the large number of tracks needed for the LED segment controller, digital and analog tracks are relatively close together. That said, I tested the same design with separate analog ground (join under the ADC) and couldn’t find measurable difference.

Notice: ADS1232 does not communicate using standard SPI. Please see my (or any other) library.

RC filtering

Finally, I settled with the reference design and parts. The only exception is that I replaced the small 100pF PPS (ECH-U1C101GX5) with NP0 (GRM2165C1H101FA01D) caps to lower the cost a little.

Why those tiny feed throughs?

I cannot measure/see any difference with/without them, but TI knows best (they have them on the reference design). Run a jumper cable across if you don’t have them or even edit the pcb and remove them completely (if you can’t ask me – I can make a new revision).

Bottom Layer

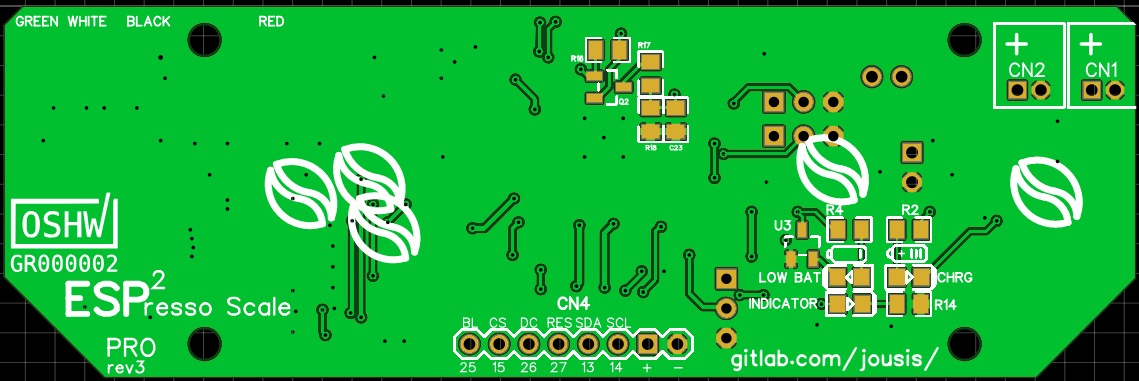
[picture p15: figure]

Battery warning (works also while on deep sleep) & LEDs

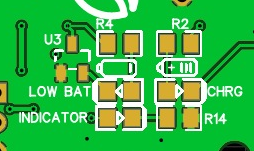
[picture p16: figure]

U3 is a simple voltage supervisor circuit that will light LED2 (LOW BAT) when LDO output is <2.99 volts. Use a low power LED because it might stay on for some time. Our MCU will die around 2.8V.

CHRG LED (LED1) is enabled when …you guessed it… battery is charging.

INDICATOR (LED3) is connected to mcu IO and you can use it in any way you like.

All leds are placed closely together so you can design a small “window” on your case. For the same reason, there are no indicators/names on the final pcb (silkscreen) apart from the two battery icons.

CN4 is for OLED/TFT screens and I have labeled the pins for your convenience.
As is, you can connect the usual Chinese OLED modules (be careful of VCC/GND pins) and some TFT modules.

PINS

From left to right as you see on the picture above:

1. Screen Backlight control (TFT) – IO25 – solder pulldown resistor R15 if you have a TFT
2. CS – IO15 (HSPI SS)
3. DC – IO26
4. RES – IO27
5. SDA – IO13 (HSPI MOSI)
6. SCL – IO14 (HSPI SCK)
7. VCC
8. GND

Note: You must solder the R15 pulldown resistor next to the PWM pin if you want to shut down the backlight.

Tip:

In order to mount your display as close to the PCB as possible without soldering it directly to it, use 90 degree headers in a “Z” configuration.

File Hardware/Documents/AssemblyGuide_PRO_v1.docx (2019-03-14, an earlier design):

ESP²resso Scale PRO

PCB Assembly Guide (v1)

v2 coming soon

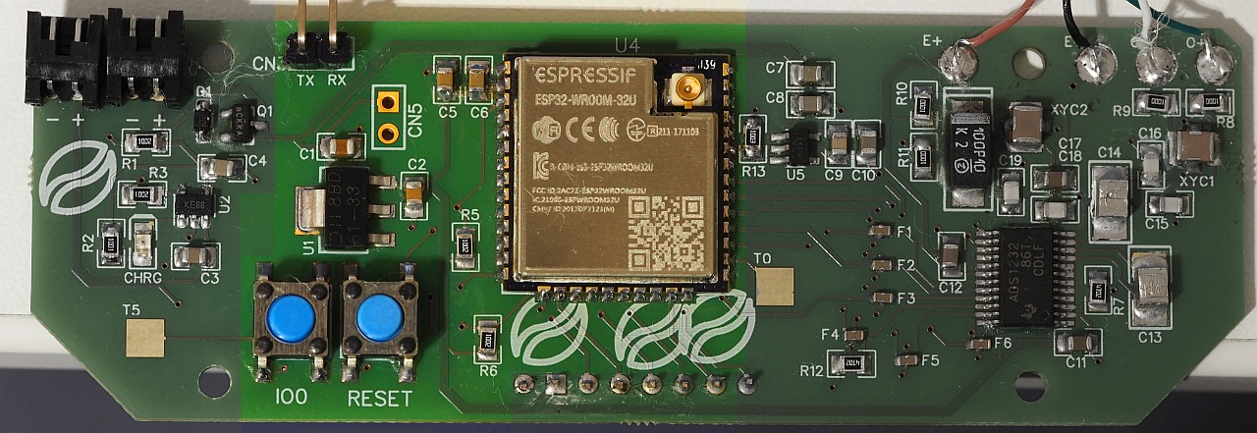
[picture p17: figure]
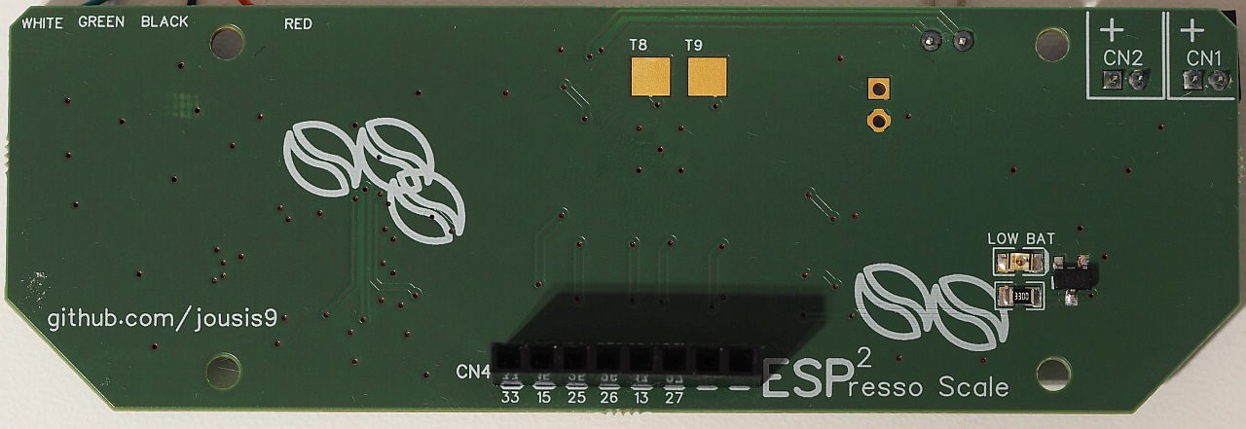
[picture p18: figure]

With a little care, you can easily hand solder all the components. No need for hot air.

If you want to minimize the cost, all components except the ADC can be replaced with cheaper alternatives. Try to avoid very cheap components in the analog section (RC filtering) or you might lose some accuracy/stability.

Why “espresso” scale?
High resolution, high refresh rate needed during an espresso extraction. Apart from that, it is a normal scale.

Why “PRO”?

You can use any SPI (or I2C) screen (even TFT with backlight pin), slightly better RC filtering, speed/gain control of the ADC from the software, better separation of analog/digital tracks, power on/off of the second LDO.

Section 1 – USB / Battery Input & charging

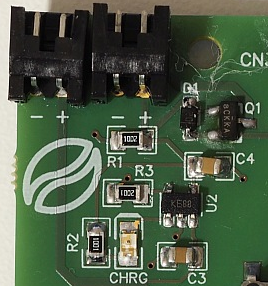
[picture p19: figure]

Battery charging circuit design: Sparkfun ESP32 Thing (https://cdn.sparkfun.com/assets/learn_tutorials/5/0/7/esp32-thing-schematic.pdf)

If you don’t care about battery / battery charging you can connect DC+5V to CN5 and do not solder any of the parts shown above.

Please see the schematics for more info.

Section 2 – LDO & MCU

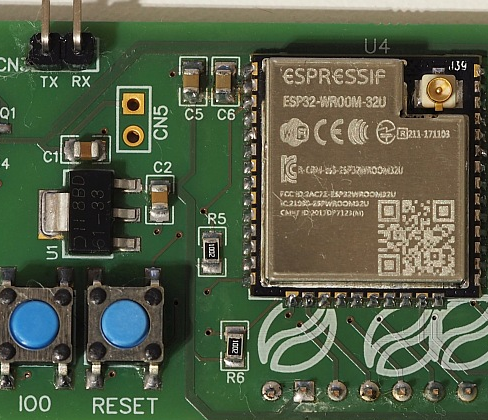
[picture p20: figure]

LDO

I have selected an 1A LDO with relatively low quiescent current, but you can replace it with an even better 500mA if you don’t intend to use Wifi. Remember that, when the esp is in deep sleep mode, the LDO will probably drain more power than the mcu.

Consider also changing package to SOT-23-5. In that case, consider 500mA TLV75533PDBVR.

CN5 is optional header, you can use it to give power to the LDO without having to connect the Section 1 part. Very handy for testing.

MCU

You can use any esp32 wroom with the same footprint (ESP32, ESP32D, ESP32U).

Why module (wroom) and not barebones chip?
Easier to solder, readily available, reasonable size.

Buttons

Warning: these buttons are taller than all the other components. New revision has the same buttons as Lunar Eclipse version. Check BOM.

Programming

The only way to program your MCU for the 1st time is through the serial connector on the bottom. There is no ftdi chip on the PCB. Afterwards, if you wish, you can setup an OTA method.

Touch Input

The exposed 2 solder pads on the top/bottom are connected to touch pins T0,T5,T8,T9. Solder a small cable and terminate it in a copper tape behind the plastic case (or any other way you might think of).

Section 3 – ADC / Load Cell

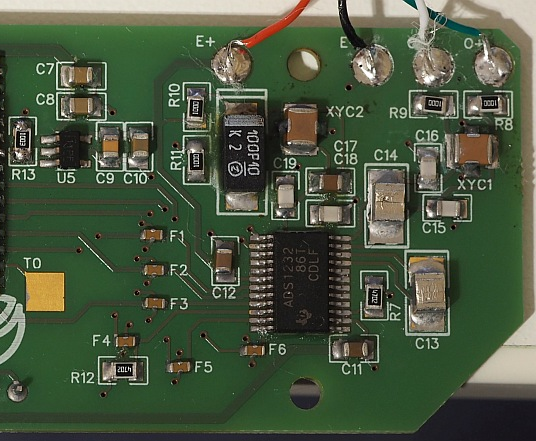
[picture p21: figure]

LDO

U5 is the local LDO for the analog +3.3V voltage used for the load cell excitation. Use high quality components on everything related to the analog circuit.

The selected LDO has its enable pin connected to the MCU (IO21). Remember to select it as output and send HIGH when you wake up and LOW when going to sleep.

If you choose another LDO, make sure that the output voltage is very stable. Every miniscule variation can lead to false readings or excessive creeping. Also, the higher the voltage, the better the stability/accuracy. If you are designing your own high precision scale that does not need to be battery operated, use 5V.

ADC

Compared to the HX711 used in almost all the cheap (and not) designs, ADS1232 from TI is very accurate and stable. Although much more expensive, for this type of scale it is an expense you will have to make. Even when heating it up it could manage 0.1g accuracy (has internal temp sensor). Kudos to TI for their awesome documentation and white papers. (notice: This project is in no way affiliated with TI)

Digital +3.3V comes from the main LDO, analog +3.3V from the local LDO. There is only one ground for both signals (analog/digital) but I tried to avoid any digital signal return path through the analog part of the ADC. Unfortunately, due to the size constraints and the large number of tracks needed for the LED segment controller, digital and analog tracks are relatively close together. That said, I tested the same design with separate analog ground (join under the ADC) and couldn’t find measurable difference.

Notice: ADS1232 does not communicate using standard SPI. Please see my library.

RC filtering

If you have experience in RC filtering, please redo the calculations and find better values for R/C. I tried my best 😊
Otherwise, please use high quality caps here or you will lose accuracy and possibly suffer from more creeping than you see on the demo videos.

Why X2Y and not simple feed throughs (shown on ADS1232REF)?

I wanted to test them, and I have found measurable difference in the +/-0.01 region which is of no importance to a amateur scale project like this. So, use feed through If you like or even omit them (you will lose some stability).

Why those tiny feed throughs?

I cannot measure/see any difference with/without them, but TI knows best (they have them on the reference design). Run a jumper cable across if you don’t have them or even edit the pcb and remove them completely (if you can’t ask me – I can make a new revision).

Load cell pads

Some cells have the white/green cables inverted. If you read negative values, swap red/white position.

Bottom Layer

Warning: Silk screen has the wrong pin numbers. Please see below.

U3 is a simple voltage supervisor circuit that will light LED2 when LDO output is <2.99 volts*

CN4 is for OLED/TFT screens and I have labeled the pins for your convenience.
As is, you can connect the usual Chinese OLED modules (be careful of VCC/GND pins) and some TFT modules.

PINS

From left to right as you see on the picture above:

1. Screen Backlight control (TFT) – IO25
2. CS – IO15 (HSPI SS)
3. DC – IO26
4. RES – IO27
5. SDA – IO13 (HSPI MOSI)
6. SCL – IO14 (HSPI SCK)
7. VCC
8. GND

Tip:

In order to mount your display as close to the PCB as possible without soldering it directly to it, use 90 degree headers in a “Z” configuration.

*still testing various batteries and voltage supervisors, if you have any feedback, please share.

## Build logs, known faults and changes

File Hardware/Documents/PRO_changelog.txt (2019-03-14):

v3 (in prototyping)
-(bug solved) Placed R15 pulldown on TFT backlight pin.
-(bug solved) No more in-pcb touch pads. They are unreliable in 2-layer pcb.
-(bug solved) T0 left floating. Was causing too many issues on reboot when used as touch or input pin with external modules.
-(feature) voltage divider / battery monitor circuit with mosfet with on/off control (saves power).
-(feature) 3 external digital IO connectors with VCC / IO / GND pins. Middle pin is touch pin of ESP if you want to try your luck.
-(feature) Both LDOs are now SOT-23-5 with enable pin support. Our main LDO had enable pin pulled high, analog is tied to our MCU.
-(feature) analog LDO now has series R with second CAP, if you use MLCC and want to add some R, do it.
-(feature) analog LDO now has 0805 capacitor next to the (usually NC) pin 5. If your LDO supports low noise operation with an extra cap, use it.
-(feature) low profile buttons
-(feature) indicator LED near low bat/charging LEDs (use low power LED)
-1uF feedthrough caps on analog reference/input (ADS1232 ref design).
-better positioning of 100pF filters.
-open source hardware association certification logo in silkscreen.
-X2Y tests failed and gone back to REF design. I didn't gain anything measurable and space saving was minimal.

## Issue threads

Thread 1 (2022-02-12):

I need a little help, please.

IsoEek, 2022-02-12:
jousis9 I reacently comented on your video .What version is the latest? I see three versions. I'm new to this so please bear with me. I wanted to know if I could add a usb-c to the board to charge the battery and wire it for serial communication as well? I read through the assembly guide. I was going to use a capacitive touch sensor for turning it on ad off, so do I need the two buttons, right? I don't know if I missed something there. Last question. Will I cause any more electrical noise if I delete CN4 don't need a display, and the battery monitor, indicator LED, and shrink the board down to 80mm X 40mm? Thanks in advance for any help you can provide.

jousis9, 2022-02-12:
I would suggest start with the PRO v3.
All are recent, just different designs. But PRO is easy to work with.
Unfortunately I can't help you with the USB-C part because I've never tried in any of my boards. I don't see why it would be difficult though. You can then remove the RX/TX connector as well (or keep it, just in case).
BUT, if you need a good low power performance when sleeping, be sure to select a USB controller that can shutdown completely or at least draw a little uA.

You can shrink the board easily if you remove the unneeded parts, just try to keep the scale circuity separated as is it on the original circuit. You won't have any real issues with the scale. You might just loose some accuracy but I even doubt that.

I never had good luck with the capacitive buttons on the ESP32 though. They work, BUT I find them inconsistent and with low sensitivity. I prefer the cheap modules that are sold for $1 everywhere.

I have another version using LIFEPO battery (w/o charging) but never really tested it for accuracy.
https://aisler.net/p/ADPKETCO
I also uploaded the gerber & easy eda files but since it's not tested enough, please review them carefully.

I don't think it is what you need, but as an example, even as cramped as that it was fine.
The other mini pcb also, the featherwing works fine.
https://github.com/jousis9/scale-featherwing.

Feel free to ask anything else.

IsoEek, 2022-02-12:
Thank you for your response, I really appreciate it. I have a friend who is
helping me when he can. He has two months left and then he graduates. Why
is 3 easier to work with?

I did a little looking around and think I might have it worked out for the
USB-C. I'll have my friend check it out. I'll let you know how it goes.

"be sure to select a USB controller that can shutdown completely or at
least draw as little uA." Are you referring to the microcontroller? I don't
understand.

Lol. The cheap capacitive touch sensor is what I meant.

 I'll keep in mind spacing the ad1232 away from everything else.

I love the miniscale. That's awesome. I think I want to make one and try
that later.

Maybe testing a featherwing scale with a HUZZAH32 feather would be good
before I go all in. I need a bluetooth scale for pulling things apart so I
can measure maximum working load. I read that the Lonic was working with
Bluetooth. So, I should be able to do the same thing with v3 or any of the
boards, if I install the firmware and update the pinouts? I'm probably
missing something. Do you take donations? I've wasted enough of your time.
Thanks again.

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

IsoEek, 2022-02-13:
That all makes perfect sense. You are very kind and helpful. I'll definitely share with you so you can update the board. I will go ahead and put it all together and start testing. Thanks again.

Closed 2022-02-13.

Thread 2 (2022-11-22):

Repeatability

runningtoy, 2022-11-22:
Hi jousis9,
first congrats to your project it was an awesome kickstart for my fork.

My scale is complete and it's working awesome but i have one issue.

Repeatability!
If i place my weight not on the excat same position, i got different values. Not only 1% off. Fare more.

I think it's logical that it is excactly that way. But how to overcome/solve that issue? Any tweaks on the case design on your side i did not realized?

jousis9, 2022-11-22:
Yes, as you mentioned, this is a known problem, not on the code/pcb, but the case and load cell.
Unfortunately, with diy plastic cases you can't do much.
I did make some with [more traditional design](https://www.aliexpress.com/i/1005003526452362.html) and were better but I don't have scematics.

Some things to try (in that order):
A _less_ sensitive load cell would help because it would bend/deform less.
Some preloading would also help (make the top part heavier somehow.
Try a case design with a small plate on top (like on the above url), won't be as resistant but would be more stable.
Second load cell (one on the right, one on the left).

jousis9, 2022-11-22:
The case is amazing !
It should be better than the plastic one, so if you try a different (5kg maybe?) load cell it would be fine.

The problem is that I've not found the 5kg load cell acaia uses, which is very small and with minimal deformation.
There [are some pictures of it here](https://www.home-barista.com/repairs/acaia-lunar-battery-olo-bat-1-error-no-charging-t63329.html) if  you want to search aliexpress for similar. It's very good (I have an acaia).

runningtoy, 2022-11-22:
Great input. Thanks
Currently i use a 300g load cell cause it's enough (i thought) but your statement sounds logical.
Time to do some shopping on aliexpress

runningtoy, 2022-12-31:
Upgraded my load cell to a 2kg Mavin N27 and added a aluminum beam. No it's much better.
https://github.com/runningtoy/ESPresso-Scale/README.md
thanks for your support

jousis9, 2022-12-31:
Perfect!

I will monitor your repo for test results/updates.

Closed 2022-12-31.

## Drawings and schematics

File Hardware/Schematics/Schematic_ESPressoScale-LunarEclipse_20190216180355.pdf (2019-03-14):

+3.3V

+3.3VA

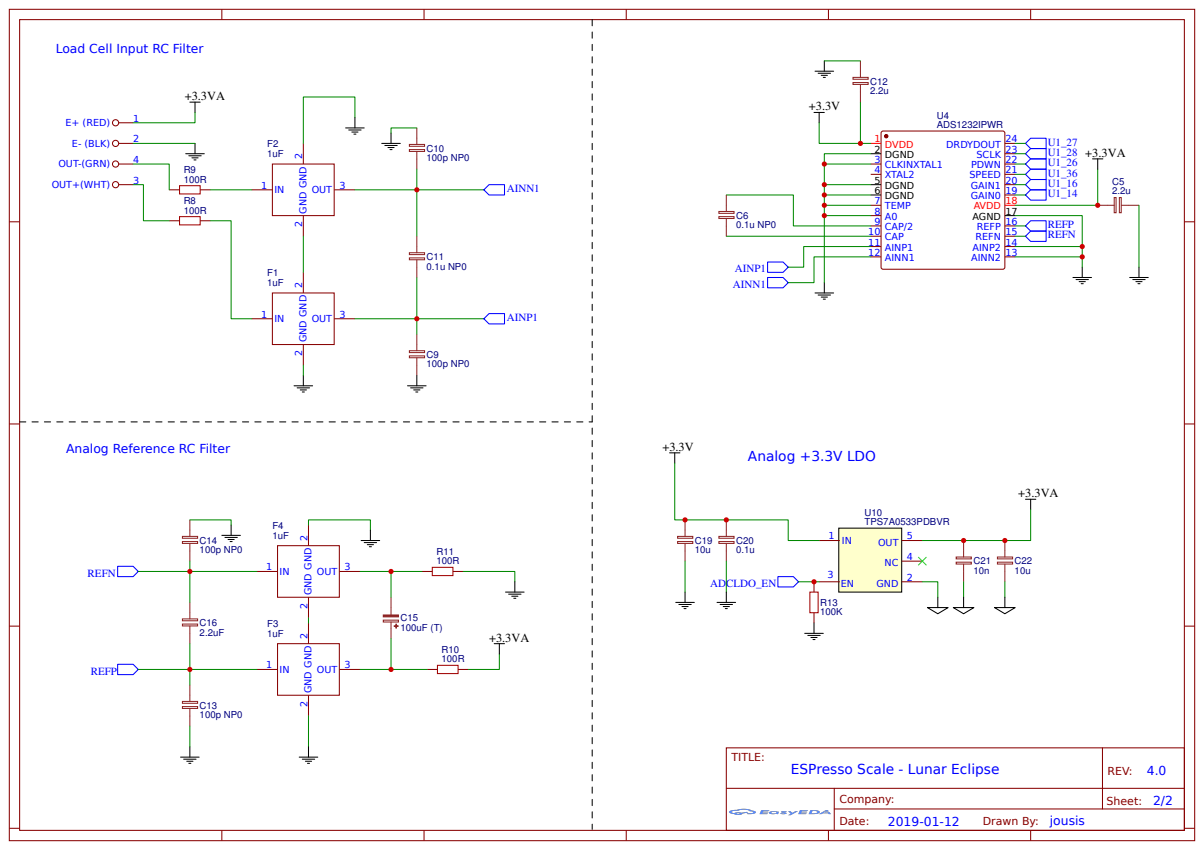
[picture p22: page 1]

Load Cell Input RC Filter

Analog Reference RC Filter

IO0 25 IO4 26 IO16 27 IO17 28 IO5 29 IO18 30 IO19 31 NC 32 IO21 33 RXD0 34 TXD0 35 IO22 36 IO23 37 GND 38

## ESP32-Wroom

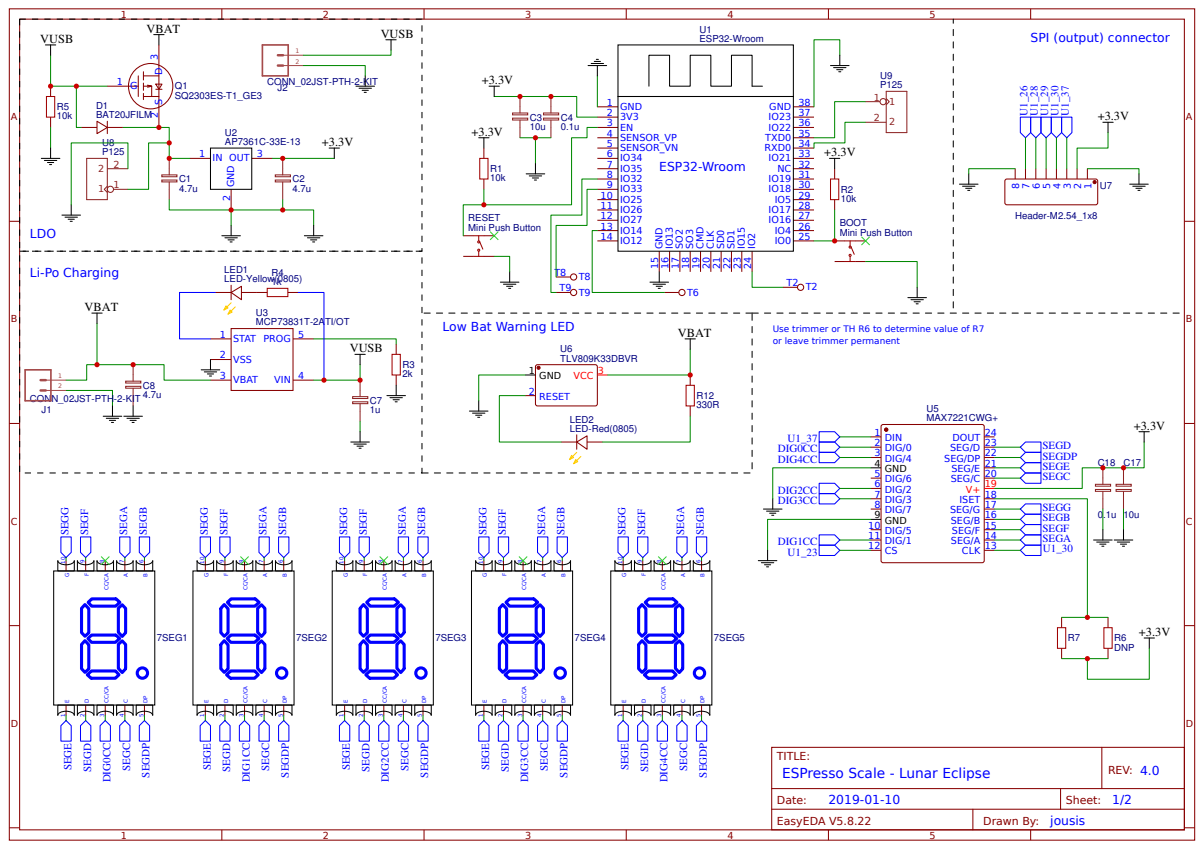
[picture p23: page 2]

RESET
BOOT Mini Push Button

Low Bat Warning LED

Use trimmer or TH R6 to determine value of R7
or leave trimmer permanent

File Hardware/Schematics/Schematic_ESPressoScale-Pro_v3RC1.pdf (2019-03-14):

## VUSB

## VBAT

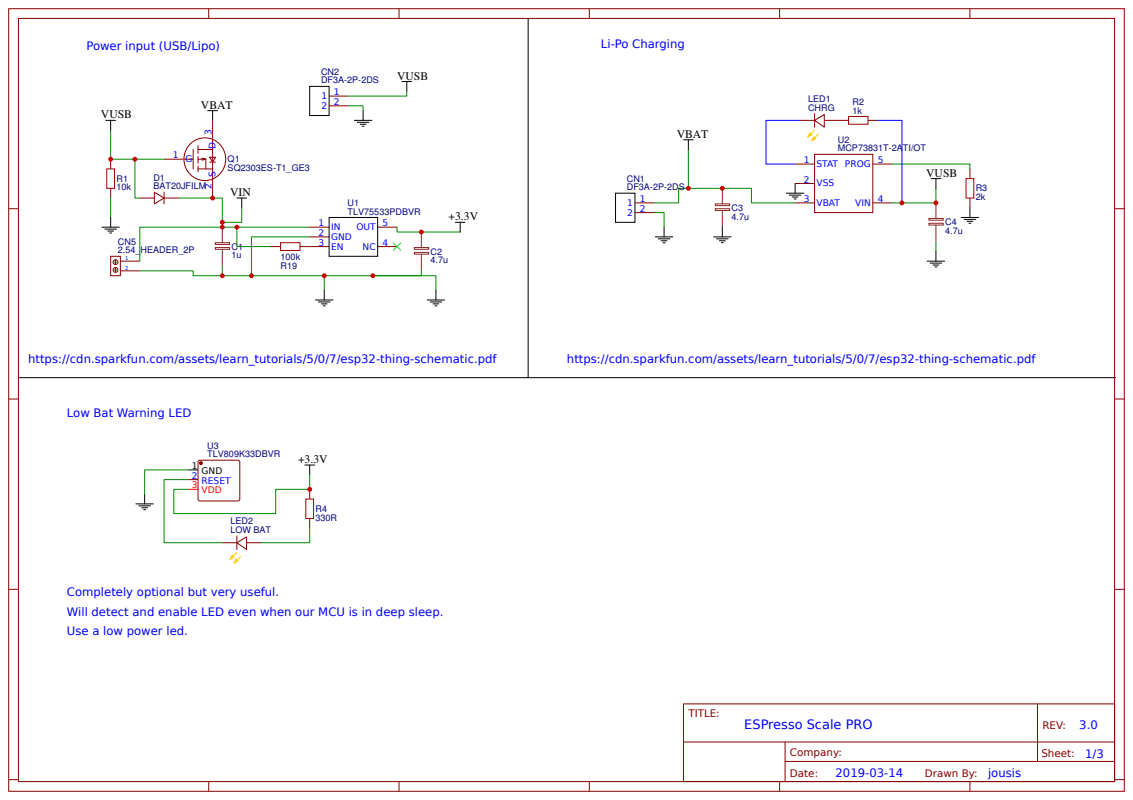
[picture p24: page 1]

Low Bat Warning LED

Completely optional but very useful.
Will detect and enable LED even when our MCU is in deep sleep.
Use a low power led.

+3.3V

+3.3V

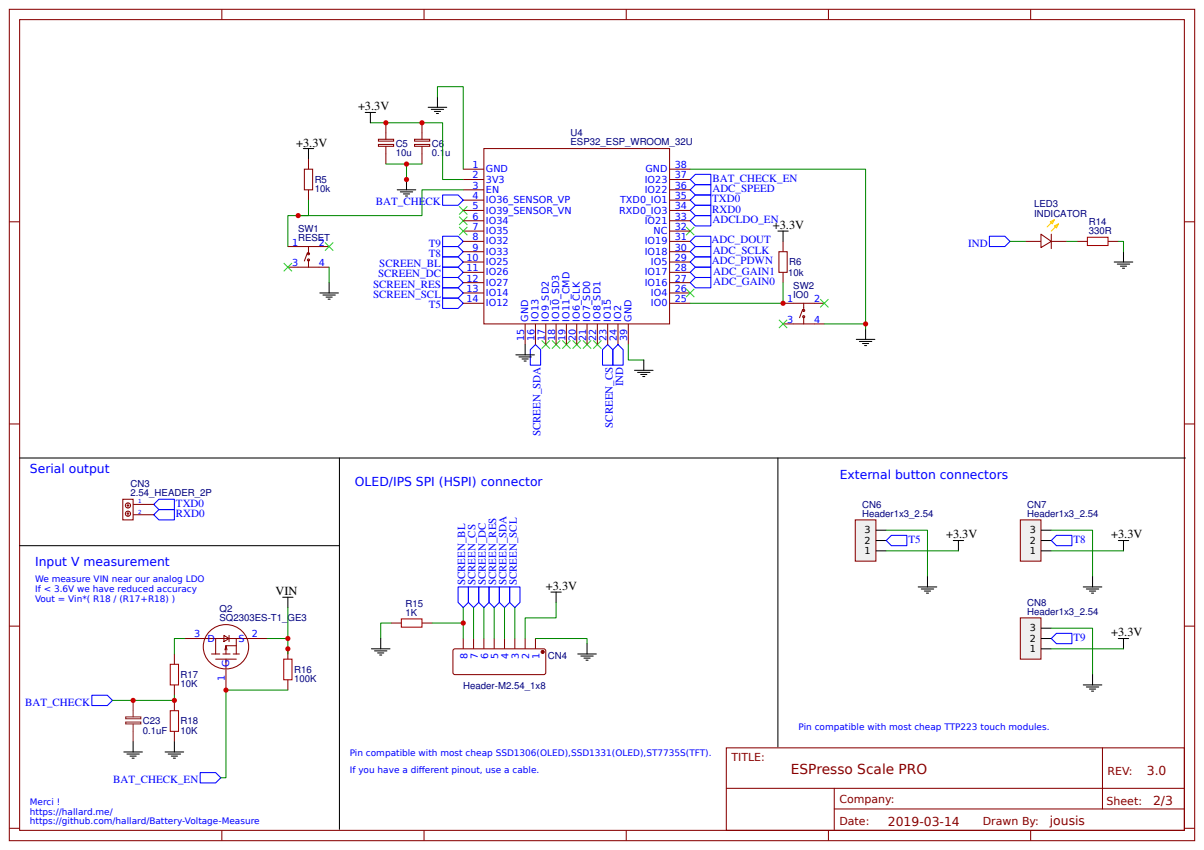
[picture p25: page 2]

OLED/IPS SPI (HSPI) connector

Input V measurement
We measure VIN near our analog LDO
If < 3.6V we have reduced accuracy
Vout = Vin*( R18 / (R17+R18) )

Pin compatible with most cheap TTP223 touch modules.

Pin compatible with most cheap SSD1306(OLED),SSD1331(OLED),ST7735S(TFT).
If you have a different pinout, use a cable.

Merci !
https://hallard.me/
https://github.com/hallard/Battery-Voltage-Measure

## VIN

+3.3VA

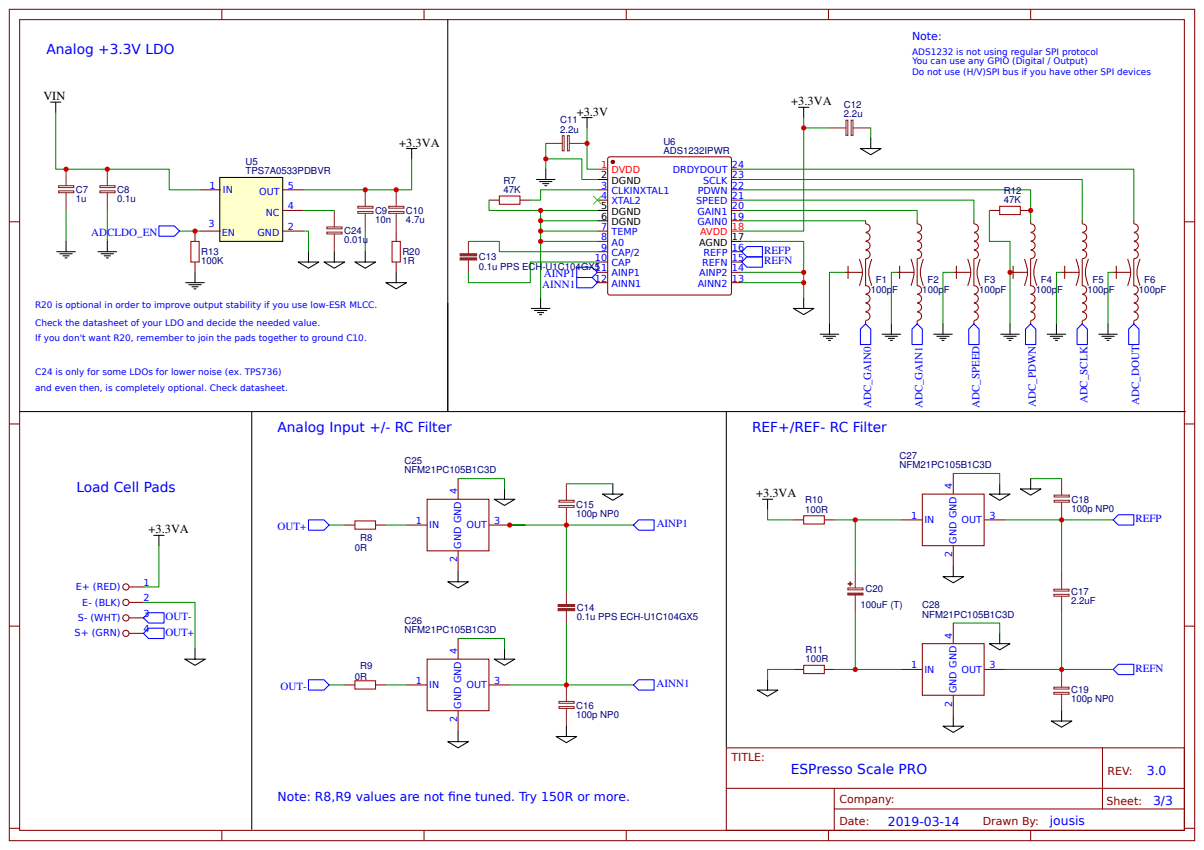
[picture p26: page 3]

Note:
ADS1232 is not using regular SPI protocol
You can use any GPIO (Digital / Output)
Do not use (H/V)SPI bus if you have other SPI devices

R20 is optional in order to improve output stability if you use low-ESR MLCC.
Check the datasheet of your LDO and decide the needed value.
If you don't want R20, remember to join the pads together to ground C10.

C24 is only for some LDOs for lower noise (ex. TPS736)
and even then, is completely optional. Check datasheet.

Note: R8,R9 values are not fine tuned. Try 150R or more.

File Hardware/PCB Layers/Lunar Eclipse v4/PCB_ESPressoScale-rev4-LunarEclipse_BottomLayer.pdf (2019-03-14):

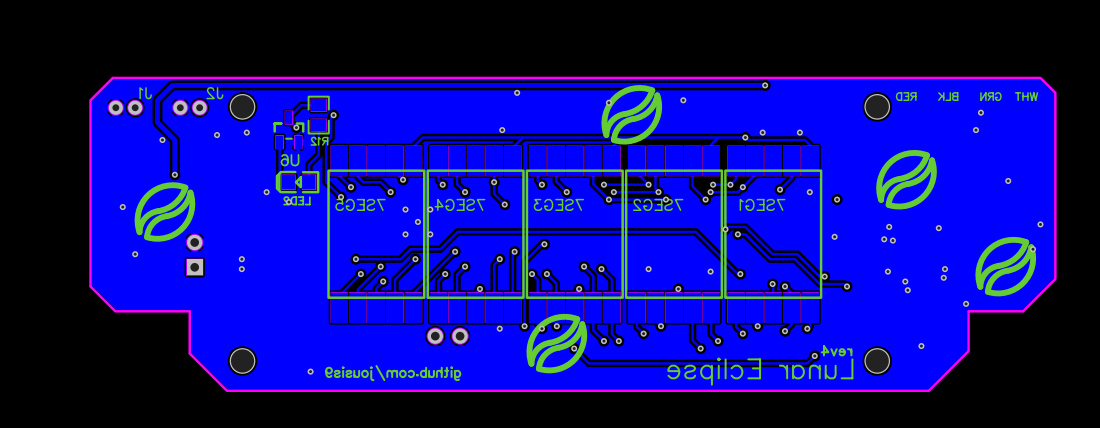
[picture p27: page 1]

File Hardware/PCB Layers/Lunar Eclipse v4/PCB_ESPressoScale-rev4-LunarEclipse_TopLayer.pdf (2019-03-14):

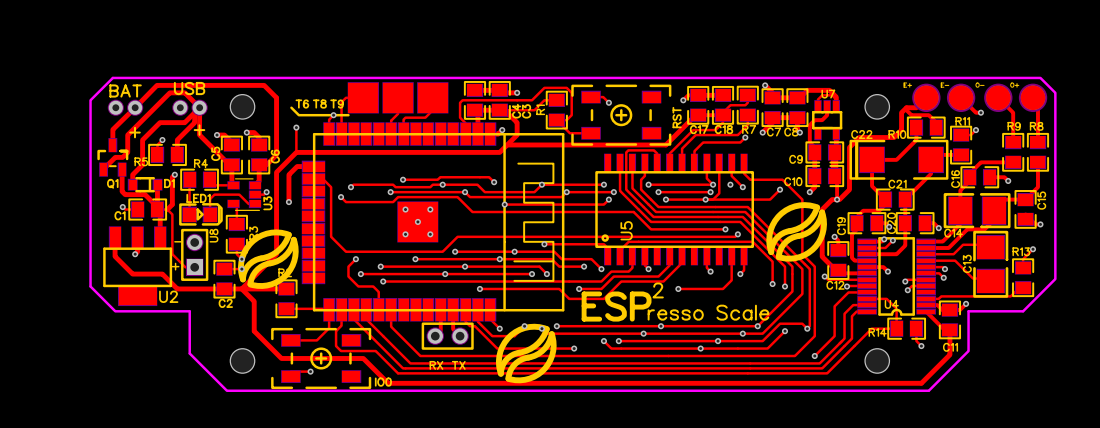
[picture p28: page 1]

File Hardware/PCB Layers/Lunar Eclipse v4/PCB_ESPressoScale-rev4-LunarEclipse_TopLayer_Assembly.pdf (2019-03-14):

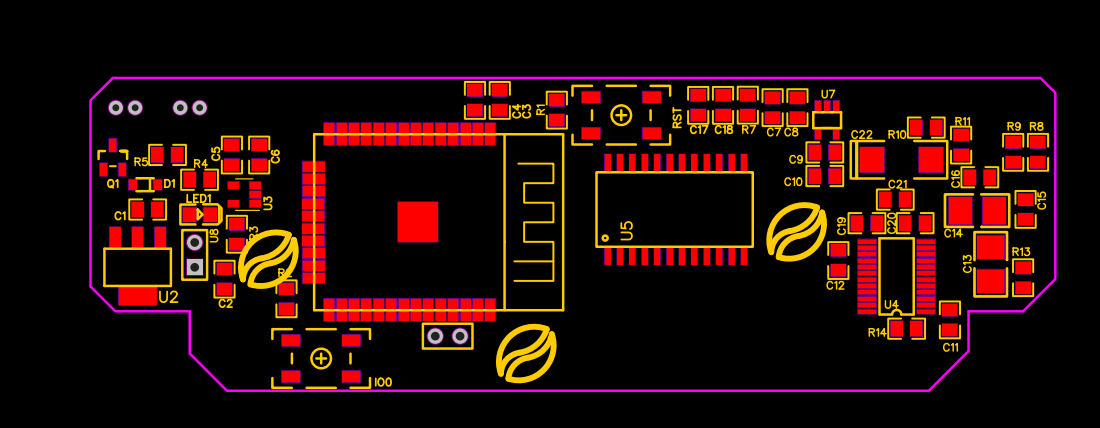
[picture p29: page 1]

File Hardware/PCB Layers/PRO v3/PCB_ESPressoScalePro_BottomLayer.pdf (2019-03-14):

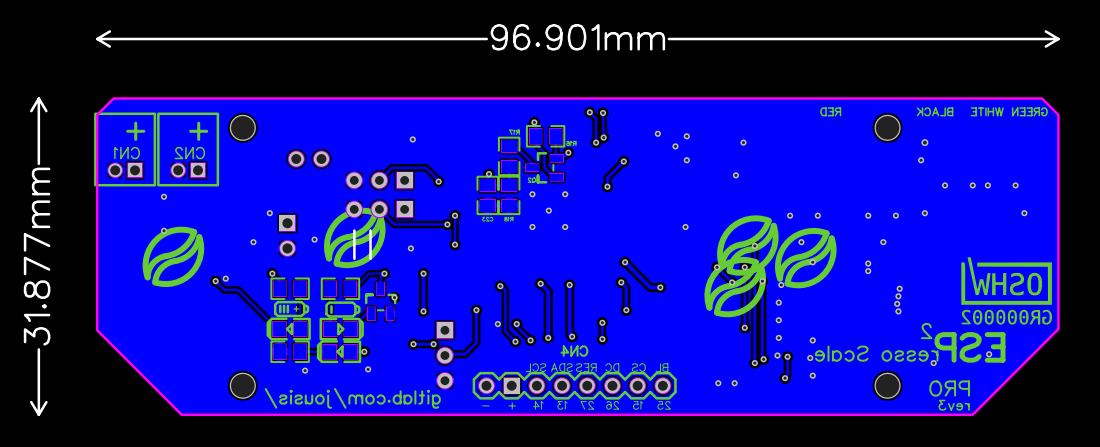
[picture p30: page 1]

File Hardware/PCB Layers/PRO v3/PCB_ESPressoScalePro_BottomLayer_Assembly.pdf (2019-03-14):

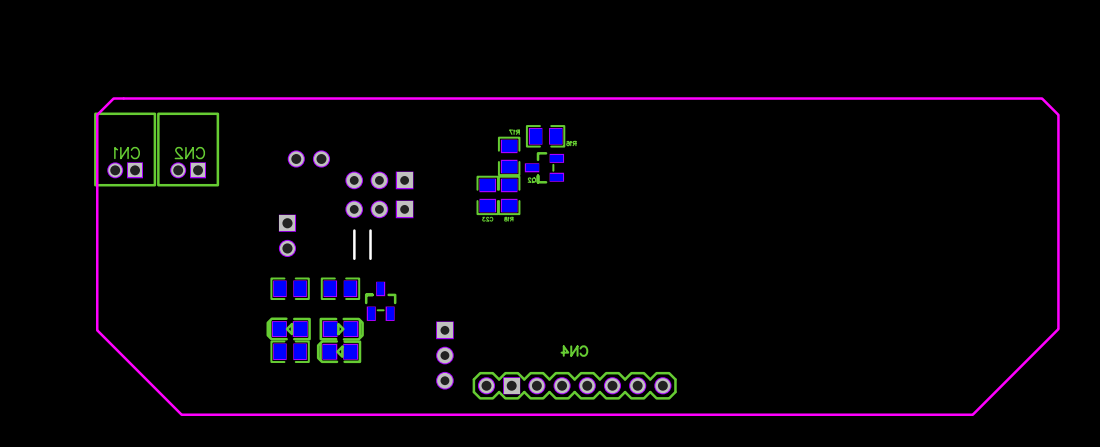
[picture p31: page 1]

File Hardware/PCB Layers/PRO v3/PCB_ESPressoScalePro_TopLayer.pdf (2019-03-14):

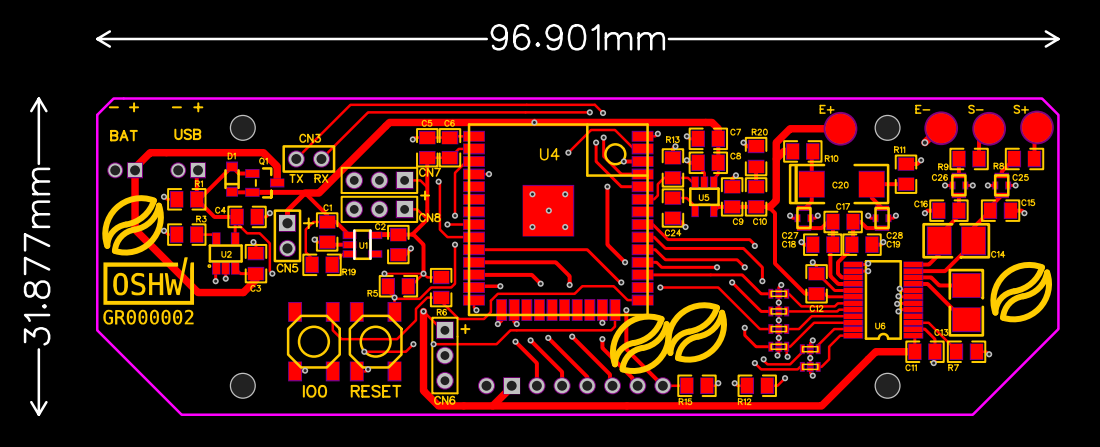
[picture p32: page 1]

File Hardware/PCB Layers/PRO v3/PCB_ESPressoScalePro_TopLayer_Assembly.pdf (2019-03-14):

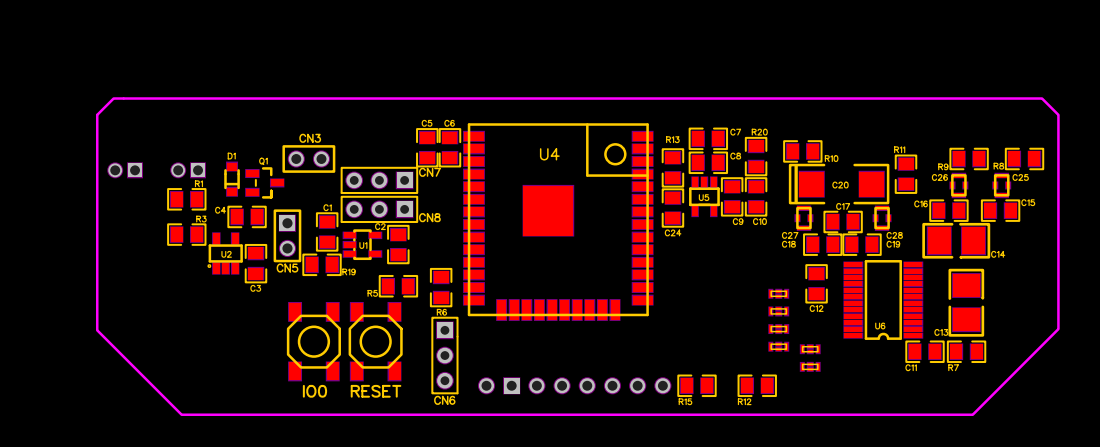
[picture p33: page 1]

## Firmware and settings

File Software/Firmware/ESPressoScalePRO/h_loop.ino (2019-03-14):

/* 
   \\\\\\\\\\\\\\\\\\\\    8.loop()    ////////////////////
*/
void loop() {
  #ifdef SERIAL
    if (Serial.available() > 0) {
      int INPUT_SIZE = 30;
      char input[INPUT_SIZE + 1];
      byte size = Serial.readBytes(input, INPUT_SIZE);
      input[size] = 0;
      char* separator = strchr(input, '=');    
      if (separator != 0)
      {
          *separator = 0;
          String command = input;
          ++separator;        
          if (strlen(separator) > 1) {
            separator[strlen(separator)-1] = '\0';
            DEBUG_PRINT("command ");DEBUG_PRINTLN(command);
            DEBUG_PRINTLN(handleCommand(command,separator));
          }
      }
    }
  #endif
  if (settings.otaUpgrade == 1) {    
    if (initialising) {
      initialising = false;
      #ifdef ST7735
        tft.fillScreen(0xFFFFFF);        
        tft.setTextSize(2);
        tft.setCursor(25, 10);
        tft.setTextColor(0x000000);
        tft.print("UPGRADE");
        tft.setCursor(40,30);
        tft.print("MODE");
        tft.setCursor(0,50);
        tft.print(wifiIP);   
      #endif
      #ifdef LEDSEGMENT
        lc.clearDisplay(LED_ADDR); 
        //uppercase u letter in digit 1
        lc.setRow(LED_ADDR,1,B00111110);
        lc.setChar(LED_ADDR,2,'P',false);
        lc.setChar(LED_ADDR,3,'d',false);
      #endif
    }
    server.handleClient();
    handlePowerButton();
    delay(100);
    return;
  }

  




  if (millis() > (lastButtonDebounceUpdate + BUTTON_DEBOUNCE_INTERVAL)) {
    lastButtonDebounceUpdate += BUTTON_DEBOUNCE_INTERVAL;
    if (POWER_BUTTON_PIN>0){ handlePowerButton(); }
    if (TARE_BUTTON_PIN>0){ handleTareButton(); }
    if (SECONDARY1_BUTTON_PIN>0){ handleSecondary1Button(); }
  }



  if (lightSleep && wakeup) {    
    wakeUpFromLightSleep();
  }

  if (snooze && wakeup) {
    snooze = false;
    wakeup = false;
    #ifdef ST7735
      ledcWrite(1, TFT_FULL_BRIGHTNESS);
    #endif
    #ifdef LEDSEGMENT
      lc.setIntensity(LED_ADDR,LED_BRIGHTNESS_HIGH);
    #endif
    lastActionMillis = millis();
  }
  

  // !lightSleep if
  // Don't do any of the following if already sleeping in order to conserve power
  // If you need something to update during light sleep, remove it from the following if
  // The only way to wake up from light sleep is if you set wakeup = true , ex. from a button or from touch interrupt (or any other interrupt)
  // PRO pcb consumes about 40mA during light sleep
  if (!lightSleep) {
    //While initialising, keep taring... (you can comment that, ADS1232 is fine with only the basic initialising done on the library)
    if (millis()>INITIALISING_SECS*1000 && initialising) {
      initialising = false;
      #ifdef ST7735
        tft.fillScreen(0xFFFFFF); //black
      #endif
    }
    if (initialising) {
      beginTare = true;     
      #ifdef LEDSEGMENT
        lc.clearDisplay(LED_ADDR); 
        lc.setChar(LED_ADDR,0,'0',false);
        lc.setChar(LED_ADDR,1,'5',false);
        lc.setChar(LED_ADDR,2,'E',false);
        lc.setChar(LED_ADDR,3,'5',false);
      #endif
    }
  
  
    if (beginTare) {
      beginTare = false;
      scale.calibrateADC();
      scale.tare();
      DEBUG_PRINTLN("taring...");
    }
    
    double grams = 0;
    grams = scale.readUnits(settings.readSamples);   

    DEBUG_PRINT(grams);DEBUG_PRINT("g");
    if (scale.hasSettled) {
      DEBUG_PRINT(" (s) - (");    
    } else {
      DEBUG_PRINT(" - (");
    }
    DEBUG_PRINT(scale.lastTareWeightRounded);DEBUG_PRINT("g)   ///   ");
    DEBUG_PRINT(scale.roc);DEBUG_PRINT("g/s // ");
    DEBUG_PRINT(scale.getAdcActualSPS());DEBUG_PRINTLN("SPS");

    if (calibrateToUnits > 0.0) {
      lastActionMillis = millis();
      DEBUG_PRINT("should calibrate to ");DEBUG_PRINTLN(calibrateToUnits);
      #ifdef ST7735
        tft.fillScreen(0xFFFFFF); //black
        tft.setTextColor(0x000000);
        tft.setTextWrap(true);
        tft.setTextSize(1);
        tft.setCursor(1, 10);
        tft.print("Place ");
        tft.setCursor(5, 30);
        tft.print(calibrateToUnits);tft.print("g");
        tft.setCursor(1, 50);
        tft.setTextSize(1);
        tft.print("in the scale and wait");
      #endif
      #ifdef LEDSEGMENT
        writeTo7Seg(calibrateToUnits,6,0);
        lc.setChar(LED_ADDR,0,'C',false);
      #endif
      
      scale.calibrate(calibrateToUnits,30000,0.05);
      DEBUG_PRINT("our old calfactor ");DEBUG_PRINT(settings.calFactorULong/10.0);
      settings.calFactorULong = (uint32_t)(scale.getCalFactor()*10.0);
      DEBUG_PRINT(" our new calfactor ");DEBUG_PRINTLN(settings.calFactorULong/10.0);
      settings.saveSettingULong("calFactorULong",settings.calFactorULong);
      calibrateToUnits = 0.0;
      #ifdef SSD1306
          oled.clearDisplay(); 
          oled.setTextSize(2);
          oled.setTextColor(WHITE);
          oled.setCursor(30,40);
          oled.print("THANKS !");
          oled.display();
      #endif
      #ifdef ST7735
        tft.fillScreen(0xFFFFFF); //black
        tft.setTextColor(0x000000);
        tft.setTextWrap(true);
        tft.setTextSize(2);
        tft.setCursor(1, 30);
        tft.print("THANKS !");
        delay(1000);
        tft.fillScreen(0xFFFFFF); //black
      #endif
    }
  
    if (initialising) {
      lastActionMillis = millis();
      scale.tare();
    }
  
  
    if (millis() > (lastDisplayUpdate + DISPLAY_REFRESH_INTERVAL)) {
      lastDisplayUpdate += DISPLAY_REFRESH_INTERVAL;      
      if (!initialising) {
        #ifdef SSD1306
          oled.clearDisplay(); 
          oled.setTextSize(2);
//          oled.setTextColor(WHITE);
          oled.setCursor(0,20);          
          oled.print(String(grams)+ "g");
          oled.display();
       #endif
        #ifdef SSD1331
          oled.fillScreen(BLACK);
          oled.setTextScale(2,2);
          oled.setTextColor(YELLOW);
          oled.setCursor(0,20);          
          oled.print(String(grams)+ "g");
       #endif
       #ifdef ST7735       
          //tft.fillScreen(0xFFFFFF); //black
          tft.fillRect(0,20,160,25,0xFFFFFF);
          tft.setTextWrap(false);
          tft.setTextSize(3);
          tft.setCursor(10, 20);
  //        tft.print(String(grams)+ "g");    
          char buffer[10];
          for (byte i=0;i<sizeof(buffer);i++) {
            buffer[i] = 'c';
          }
          dtostrf (grams, 6, scale.decimalDigits, buffer);        
          for (byte i=0; i<sizeof(buffer);i++) {
            if ( buffer[i] != 'c'){
              tft.print(String(buffer[i]));
            } else if (buffer[i] == 'c') {
              tft.print("g");
              break;
            }
          }
       #endif    
       #ifdef LEDSEGMENT
          writeTo7Seg(grams,6,scale.decimalDigits);
       #endif
          
      } 
  
    }
    


  if (settings.bleEnabled) {
    //BLE notify loop 
    if (deviceConnected && (millis() > lastBleUpdate + BLE_REFRESH_INTERVAL)) {
      lastBleUpdate += BLE_REFRESH_INTERVAL;
          //pWeightCharacteristic->setValue(grams);
          String gramsstr = String(grams);
          pWeightCharacteristic->setValue(gramsstr.c_str());
          pWeightCharacteristic->notify();
    }
      // BLE disconnecting
      if (!deviceConnected && oldDeviceConnected) {
          delay(500); // give the bluetooth stack the chance to get things ready
          pServer->startAdvertising(); // restart advertising
          DEBUG_PRINTLN("start advertising");
          oldDeviceConnected = deviceConnected;
      }
      // BLE connecting
      if (deviceConnected && !oldDeviceConnected) {
          // do stuff here on connecting
          oldDeviceConnected = deviceConnected;
      }
  }
    

    if (scale.hasSettled) {
      //enable the following check if you want to only snooze when there is no weight on the scale
//      if (fabs(grams) < 10){
////        DEBUG_PRINTLN("don't leave me alone please");
//      } else {
//        wakeup = true;
//        lastActionMillis = millis();      
//      }
    } else {
      wakeup = true;
      lastActionMillis = millis();
    }



    if (settings.lightSleepTimeout > 0 && (millis() - lastActionMillis) >  settings.lightSleepTimeout*10000) {
      initiateLightSleep();
    }

    
    if (settings.snoozeTimeout > 0 && !snooze && ((millis() - lastActionMillis) >  settings.snoozeTimeout*10000)) {
      #ifdef ST7735
        ledcWrite(1, TFT_DIM_BRIGHTNESS); // dimming           
      #endif         
      #ifdef LEDSEGMENT
        lc.setIntensity(LED_ADDR,LED_BRIGHTNESS_LOW);        
      #endif
      DEBUG_PRINTLN("ZZZZzzzzz");
      snooze = true;
      wakeup = false;
    }

    
  //END OF !lightSleep if   
  }


  if (settings.deepSleepTimeout > 0 && (millis() - lastActionMillis) >  settings.deepSleepTimeout*10000) {
    initiateDeepSleep();
  }

  if (snooze) {
    delay(250);
  }
  if (lightSleep) {
    delay(1000);
  }

}

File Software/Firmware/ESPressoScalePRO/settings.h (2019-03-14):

/*  
  ESPresso Scale
  Created by John Sartzetakis, Jan 2019
  Released into the public domain.
  https://gitlab.com/jousis/espresso-scale
*/

#ifndef SETTINGS_h
#define SETTINGS_h

#include <Preferences.h>

class SETTINGS
{

  public:
    SETTINGS();
    byte otaUpgrade = 0; //OTA is enabled by long touching T8 & T9 during startup
    String wifiHostname = ""; //check out the default values at resetSettings()
    String wifiSSID = "";
    String wifiPassword = "";
    
    byte bleEnabled = DEFAULT_BLE_ENABLED;

    byte snoozeTimeout = DEFAULT_SNOOZE_TIMEOUT;
    byte lightSleepTimeout = DEFAULT_LIGHT_SLEEP_TIMEOUT;
    byte deepSleepTimeout = DEFAULT_DEEP_SLEEP_TIMEOUT;
    byte scaleMode = DEFAULT_SCALE_MODE;
    byte scaleUnits = DEFAULT_SCALE_UNITS;
    byte zeroTracking = DEFAULT_ZERO_TRACKING;
    byte stableWeightDiff = DEFAULT_STABLE_WEIGHT_DIFF;
    byte zeroRange = DEFAULT_ZERO_RANGE;
    byte fakeRange = DEFAULT_FAKE_STABILITY_RANGE;
    byte sensitivity = DEFAULT_SENSITIVITY;
    byte smoothing = DEFAULT_SMOOTHING;
    byte adcSpeed = DEFAULT_ADC_SPEED;
    byte decimalDigits = DEFAULT_DECIMAL_DIGITS;
    byte readSamples = DEFAULT_READ_SAMPLES;
    byte slBtnPress = DEFAULT_STATUS_LED_BUTTON_PRESS;
    byte slMaxVIN = DEFAULT_STATUS_LED_MAX_VIN;
    byte batReadInterval = DEFAULT_BATTERY_LEVEL_READ_INTERVAL;
    uint32_t calFactorULong = DEFAULT_CAL_FACTOR_ULONG;
    void clearEEPROM();
    void resetSettings();
    bool loadSettings();
    void saveSettingByte(const char* key, uint8_t value);
    void saveSettingULong(const char* key, uint32_t value);
    void saveSettingString(const char* key, String value);
    void saveSettings();
  
  protected:
    Preferences preferences;
    //If you change anything in the EEPROM save function change the revision/...
    //and alter the reading function accordingly (optional)
    const byte EEPROM_STRUCT_VERSION_MAJOR = 0;
    const byte EEPROM_STRUCT_VERSION_MINOR = 0;
    const byte EEPROM_STRUCT_VERSION_REVISION = 1;
    
    ///// DEFAULT SETTINGS /////
    const byte DEFAULT_SNOOZE_TIMEOUT = 0; //3 = 30seconds, 0=disabled, in 10*seconds, dims the display, inserts 250ms delay in the loop=> approx 4 ADC reads per second
    const byte DEFAULT_LIGHT_SLEEP_TIMEOUT = 0; //6 = 1min, 0=disabled, in 10*seconds, shuts down ADC using its power pin (not the LDO) and dims the display
    const byte DEFAULT_DEEP_SLEEP_TIMEOUT = 0; //12 = 2mins, 0=disabled, in 10*seconds, shuts down ADC LDO,display and puts ESP32 to deep sleep. Consumes very little power. This is essentialy our power off mode.
    const byte DEFAULT_SCALE_MODE = 0; //0 = nothing special , 1 = auto tare
    const byte DEFAULT_SCALE_UNITS = 0; //0=grams , nothing else is implemented for now
    const byte DEFAULT_ZERO_TRACKING = 0; //in centigrams, 0=disabled
    const byte DEFAULT_SENSITIVITY = 255; //1 = minimum, best for 80SPS, 255 = max, best for 10SPS
    const byte DEFAULT_SMOOTHING = 1; //1 = enabled,0=disabled
    const byte DEFAULT_ADC_SPEED = 10; //10 or 80
    const byte DEFAULT_DECIMAL_DIGITS = 1; //the final rounding before showing to the display
    const byte DEFAULT_BLE_ENABLED = 1;
    const byte DEFAULT_READ_SAMPLES = 1; //how many samples per read
    const byte DEFAULT_STATUS_LED_BUTTON_PRESS = 1; //switch on led on button press
    const byte DEFAULT_STATUS_LED_MAX_VIN = 0; //keep led on when analog VIN >4.3V
    const byte DEFAULT_BATTERY_LEVEL_READ_INTERVAL = 0; //in seconds, not in snooze/standby/deep sleep. By default battery level is only read on startup and if mobile app asks.
    
    const uint32_t DEFAULT_CAL_FACTOR_ULONG = 14000; //actual calfactor you want for your load cell * 10.
    const String DEFAULT_WIFI_HOSTNAME = "OSES";
    const String DEFAULT_WIFI_SSID = "js-iot";
    const String DEFAULT_WIFI_PASSWORD = "iotiscool!22"; //don't worry, I did not forget that :D
    
    
    const byte DEFAULT_STABLE_WEIGHT_DIFF = 5; //in centigrams, 5 is ok for 10SPS and 80 with filtering if using a good load cell
    const byte DEFAULT_ZERO_RANGE = 5; //in centigrams
    const byte DEFAULT_FAKE_STABILITY_RANGE = 0; //in centigrams
};

#endif
